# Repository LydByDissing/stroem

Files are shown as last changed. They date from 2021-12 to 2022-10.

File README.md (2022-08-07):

# STRØM
**An Open Wifi Speaker**

The _Strøm_ open source speaker project have been started with the main goal of creating a fully functional "wifi speaker", but as an open sourced product.

## License
This project and all it's work are licensed under the [Creative Commons Attribution-ShareAlike 4.0 International License](http://creativecommons.org/licenses/by-sa/4.0/) license.




## Getting started

### Checking out the repository
As this project uses the git `submodule` feature to fetch all the needed source files, one would need to have this in mind when performing the checkout.

To checkout everything - including all submodules - the following snippet are handy:
```
git clone --recurse-submodules -j$(nproc) https://github.com/LydByDissing/stroem.git
```

## Project description and Design Goals
As mentioned above, this project aims at designing a **wifi speaker**, capable of streaming audio using **Bluetooth** and **Spotify Connect**.

The primary design goals of the _Strøm_ speaker are:

* Minimalistic design language
* Playback via Spotify Connect and Bluetooth
* Wall mountable
* Sustainable materials
* Open Source

Making it a modern, minimalistic and fully capable speaker. Further requirement details can be found in the [requirements document](https://stroem.readthedocs.io/en/latest/requirements.html).

Besides making a modern and capable wifi speaker we are also aiming at validating the concept of "local manufactoring" - how we exactly are going to succeed with this are still an unanswered questions; see [issue #5](https://wikifactory.com/+opennext/lydbydissing/issues/local-production-but-how) for further discussions on the matter.

## Open Next Demonstrator
This project takes part in Open Next 2022 as a demonstrator project - one of twelve to be exact.
Most Strøm and Open Next communication will happen over at [this](https://wikifactory.com/@sidsel/osd-platform-for-maker) page.

## Project Documentation

The main project documentation and any permanent documentation are written in the `reStructuredText` (`.rst`) format, using the [Sphinx documentation framework](https://www.sphinx-doc.org/en/master/).

The code resides in the Strøm GitHub repo ([LydByDissing/stroem](https://github.com/LydByDissing/stroem)) and the compiled documentation are available over at Read The Docs: [stroem.readthedocs.io](https://stroem.readthedocs.io/).

## Contributions and collaboration
We love contributions! And all forms of contributions and collaborations are welcome.

The development of the speaker and most of the involved parts are tracked here at [LydByDissing/stroem](hhttps://github.com/LydByDissing/stroem).
The main documentation of the project, the parts and the assembly process and any permanent documentation are documented using the Sphinx documentation framework as mentioned above.

### Want to participate, but not sure where to start?
Take a look at one of the open [issues](https://github.com/LydByDissing/stroem/issues) already created and chip in with your knowledge and experience. Sometimes all it takes is a single comment, to push a someone else in the right direction; so don't hold yourself back.

Or read our [contributing guidelines](https://github.com/LydByDissing/stroem/blob/main/CONTRIBUTING.md) for further details on how to be involved.

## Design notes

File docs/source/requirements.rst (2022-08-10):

.. _Requirements:

Requirements
############
The main goal of the *Strøm* open source speaker project are to create a fully functional and open source "wifi speaker".

The Speaker concept
===================
The primary features of the *Strøm* speaker are:

* Minimalistic design language
* Playback via Spotify Connect and Bluetooth
* Wall mountable
* Sustainable materials
* Open Source

Making it a modern, minimalistic and fully capable speaker.

Design Goals
============
The following parameters are used as design goals. These are not *hard* requirements, but reflects the ideal characteristics of the final speaker.

Sustainability
**************
It is important to use materials that are produced and sourced using sustainable methods, as well as using sustainable productions methods of the speaker itself.
A non exhaustive lists of considerations:

* The cabinet must primarily be made out of wood

  * like MDF and plywood
* No plastic
* Built to be repairable

Making a 100% sustainable active speaker is, however, not 100% realistic as there isn't any fully sustainable PCB's. At least not readable available.

Cabinet
*******
The design of the cabinet must reflect a minimalistic design approach. This means a small physical form factor and a minimalist visual appearance.
A non exhaustive lists of considerations:

* Small form factor
* Shallow cabinet for better on-wall placement
* Ultra mat finish of the cabinet
* Cloth covered drivers

Acoustics
*********
With this project it is not the goal to create another `boombox <https://en.wikipedia.org/wiki/Boombox>`_, with over attenuated lows (bass) and highs (treble) as this will quickly result in listening fatigue. This is also called a `smiley face curve <https://en.wikipedia.org/wiki/Smiley_face_curve>`_.

However a slight bass boost at lower SPL levels to accommodate for the non-linear human hearing will make the speaker sound natural at lower sound pressure levels (SPL). This boost should be less pronounced at higher SPL levels; the dynamic part of this requirement can become hard to realize, but it will make for a much more appealing listening proposition.
A non exhaustive lists of further considerations:

.. acoustic-requirements-start

* Max SPL of 100dB
* Frequency range: 80Hz - 17kHz; ±3dB
* Reasonable flat response; within ±4dB
* High speech intelligibility
* SPL dependent bass boost to match the nonlinearity of the human hearing

.. acoustic-requirements-end

Below each of the technical design goals are unwrapped to explain what they mean and how the voicing process is used to implemented these requirements.

High maximum SPL
----------------
:abbr:`SPL (Sound Pressure Level)` is a measure of "how loud" a sound is. And the maximum SPL of a speaker tells something about how loud a speaker is capable of playing.

Usually the SPL is measured at a distance of one meter [m]. The unit of SPL is decibel [dB].

The Strøm speaker isn't a large speaker, but it should still be a capable speaker. A speaker that is capable of "playing loud". But as this can be hard to quantify as the perception of "loud" various a great deal from person to person. It is also highly affected by the distance between the speaker and the listener as well as it's placement in the room.
And finally this perception is impacted by any audible distortion from the speaker. The higher the distortion, the higher the SPL is perceived.

So instead of stating that the speaker must play "loud", a quantifiable number is needed.

We also want to add a few more limitations to this design goal. The maximum SPL should:

* be reachable "anywhere" on the frequency band,

* without reaching the mechanical limits of the driver,

* and should avoid clipping

We have settle on **100dB of maximum SPL** for this small speaker. This will be more than sufficient for most small and medium sized rooms.
The implementation of this requirement will affect (limit) the frequency response of the speaker. Most drivers can play down to 20Hz, but maybe not at great volume. So by limitting the frequency band we can push the drivers to higher SPL levels.

Frequency response
------------------

It should be pleasent to listen to this speaker and at the same time you should be able to get an "audio experience". So no smiley curve frequency response, nor overly exaggerated lows; i.e. this is not a boom box. We are looking to implement a "hi-fi" speaker with fairly linear frequency response.

A requirement of a linearity within ±4dB isn't perfect, but it is a pretty decent middle ground.

The better the low range extension a speaker can achieve, the more of the audio frequency range it is capable of reproducing and the more "convincing" this speaker will sound.

As small drivers are used, subwoofer levels of extension are hard to come by, so a compromise is needed. By setting the targeted -3dB point at 80Hz, this speaker will not be a bass monster, but the bass it will reproduce will be crips and undistorted.

When placed on a wall even lower frequency extension will be possible at the same (or higher) SPL.

Drivers
=======
In order to fulfill the requirements of a small form factor speaker, shallow drivers are needed. This makes it possible to minimize the overall depth of the cabinet.

Only a few really larger shallow drivers exists, which also tends to be rather expensive. They usually deliver good performance, but most of them are considered to be too expensive for this project.
In stead of using one large driver, 4 miniature full range transducers are targeted instead. This makes it possible to decrease the overall depth of the cabinet.

The following drivers are used:

* 2.5" full range driver: :ref:`SB65WBAC25-4 <full-range-driver>`.

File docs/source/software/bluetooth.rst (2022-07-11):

.. _bluetooth:

=========
Bluetooth
=========

.. epigraph::

  *"A short-range wireless technology standard that is used for exchanging data between fixed and mobile devices over short distances"*

  -- `Wikipedia <https://en.wikipedia.org/wiki/Bluetooth>`_

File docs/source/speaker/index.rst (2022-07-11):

**************************
Speaker Parts and Assembly
**************************

The speaker cabinet are constructed from MDF, as this material is well suited for this type of application. Both the low internal damping, as well as the ease of processing, of this material makes it a good choice for constructing speaker cabinets.

To minimize the overall volume of the cabinet, a sealed construction is chosen. Each driver, does in fact, have its own internal cabinet. This is done to minimize the internal interference between the drivers; hence limiting interference artifacts.

Each speaker part have its own unique ID to make it easier to identify the correct part. Externally sourced parts will likely also have a SKU or similar.

.. toctree::
   :maxdepth: 1
   :glob:

   parts/index
   assembly/index

Cabinet construction
====================

To ensure an easy assembly of the speaker cabinet, a sandwish construction is used. This makes it easy to construct the different layers and, at the same time, simplifying the construction of this semi complex cabinet. This also makes it possible to machine all the individual layers on a CNC.
This comes in handy when utilizing `decentrilized manufactoring <https://en.wikipedia.org/wiki/Distributed_manufacturing>`_.

Further details on the cabinet assembly can be found in the :ref:`assembly section <Cabinet Assembly Description>`.

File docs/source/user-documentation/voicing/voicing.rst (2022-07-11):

Voicing of the *Strøm* speaker
##############################

.. note::
  One important aspect of developing a speaker are to tune the frequency response, as well as to ensure that the drivers isn't driven over their capabilities.
  It is here the sound of the speaker is developed.

  This process is called **voicing**.

The voicing of a speaker consists of several steps and this *howto* will try to outline a few of them. The following topics will be covered below:

* Voicing goals
* Measurements
* Adjusting the response

Voicing goals
-------------

With the Strøm speaker several design goals have been defined (see more in the :ref:`Requirements` section) and those related to sound reproduction should – where applicable – be implemented through the voicing process.

The following acoustic design goals have been set for the speaker:

.. include:: ../../requirements.rst
  :start-after: acoustic-requirements-start
  :end-before: acoustic-requirements-end

Most of these design goals can be asserted using various measurement techniques.

Measuring the speaker
---------------------

What you need to measure the speaker:

* A measurement microphone like the `UMIK-1 <https://www.minidsp.com/products/acoustic-measurement/umik-1>`_ (or similar)
* Assembled cabinet with drivers
* External amplifier
* Laptop (or similar) with `Camilla DSP <https://github.com/HEnquist/camilladsp>`_ installed.
* Room EQ Wizard (`REW <https://www.roomeqwizard.com>`_)

In order to measure the speaker, make sure that you can *"answer yes"* to all of the above bullets.

What do we want to measure?
___________________________

With ``REW`` it is possible to measure a large suite of things, but bare in mind, that this program is initial created to measure rooms and not speakers.
We will use ``REW`` to perform the following measurements:
* frequency response
* phase response
* impulse response

Frequency and phase response
____________________________

We do not have easy access to an anechoic chamber, but that doesn't mean that we can't produce some useful results. And for this speaker we actively rely on the walls and boundaries to increase our bass response. So a measurement "in place" isn't actually that bad.

We have placed the microphone within 10cm from the baffle to limit the impact of reflections.

Here's the speaker measured before voicing. A single 8th order high pass (HP) filter have been added at 45Hz to protect the driver (from exceeding :math:`X_{max}`).

The frequency and phase response are depicted. It is worth noting that the results haven't been normalize, resulting in that the measured dB can't be related to anything (other than other measurements using the same setup).

.. chart:: user-documentation/voicing/80hz-target-no-filter-frequency-response.json

    Measured frequency response of an initial test cabinet. Primarily used for validation of the internal cabinet volume.

Adjusting the response
----------------------

As a developement workflow I am using the great `HEnquist/camilladsp <https://github.com/HEnquist/camilladsp>`_ project. This makes it possible to specify the filter banks as a simple YAML config file. For the initial 80Hz target tuning this file have been used: `voicing/voicing-80hz-target.yaml <https://github.com/LydByDissing/stroem/tree/main/voicing>`_.

As we can't make the bass higher – without additional :math:`X_{max}` of the driver - we need to lower the rest of the frequency response. This will lower the overall efficiency of the speaker, but result in a much more linear frequency response. See the below graph for a measurement of the inital filters applied to the signal chain.

.. chart:: user-documentation/voicing/80hz-target-initial-filters-frequency-response.json

    Measurement result when initial filtering have been applied.

The result isn't perfect but a really good starting point (and a good sounding one of that) which proves that these little drivers are pretty capable in this little cabinet.

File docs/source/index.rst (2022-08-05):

.. |date| date::

#########################################
An Open Source Wireless Streaming Speaker
#########################################

The *Strøm* open source speaker project have been started with the main goal of creating a fully functional "streaming speaker", but as an open sourced product. One that you can choose to buy fully built and tested, or choose to built it yourself.

.. toctree::
  :caption: Documentation Sections
  :maxdepth: 1

  requirements
  user-documentation/index
  repair
  end-of-life
  speaker/index
  software/index
  contributing
  license
  todo
  changelog

Read on below to get a high level `Introduction to the project`_ as a whole.

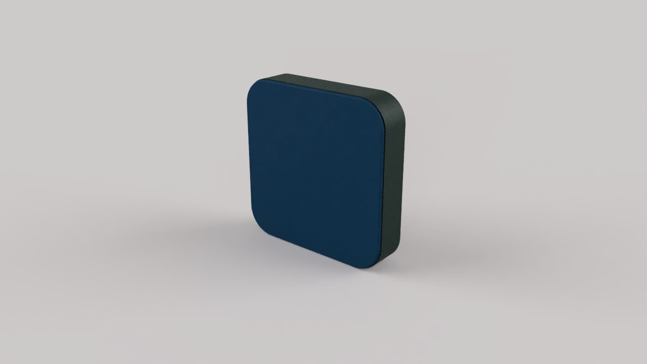
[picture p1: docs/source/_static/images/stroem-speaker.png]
Speaker


   Strøm speaker in conifer linoleum and blue fabric on the soft top.

Introduction to the project
###########################

The primary features of the *Strøm* speaker are:

* Minimalistic design language
* Playback via Spotify Connect and Bluetooth
* Wall mountable
* Sustainable materials

Making it a modern, minimalistic and fully capable speaker.

Motivation for starting the STRØM 1.0 project
*********************************************

Project goals
*************

Project history
***************

Initially started as an OPEN!NEXT demonstrator project in December 2021. The project was started by Tue Dissing.

Contributing to the project
***************************

Interested in contributing to the project? Then please take a quick look at the contribution guideline beforehand.
You find the contribution guide :ref:`here <contribution guideline>` and in the GitHub repo as well: `LydByDissing/stroem/CONTRIBUTING.md <https://github.com/LydByDissing/stroem/blob/main/CONTRIBUTING.md>`_.

Last updated
************
The mainline documentation have last been updated at |date|.

License
#######

This project is licenced under the :ref:`Creative Commons ShareAlike 4.0 license <license>`.

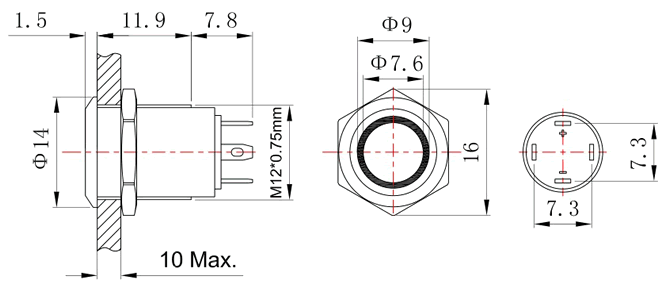
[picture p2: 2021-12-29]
docs/source/speaker/parts/push-button/12QD21-spec.gif

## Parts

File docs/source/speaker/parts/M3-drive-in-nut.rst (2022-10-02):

.. _drive-in nuts:

Drive-in Nut
************

.. sidebar:: Parts information
  :subtitle: See the below for a quick overview of the naming and ID information of this part.

  | **Part name**: *M3 Screw; 0376 3 5*
  | **Parts ID**: 6C27ST
  | **Product link**: `Würth 0376 3 5 <https://eshop.wuerth-industrie.com/Drive-in-nut-NUT-DRIVIN-A2K-H5X12-M3/03763%20%205.sku/en/US/EUR/>`_

Parts Description
-----------------
To ensure proper mounting of the speaker drivers, they are fastened using these screws and the already mounted drive-in nuts.

Please see the tables below for dimensions.

.. table:: Physical requirements

  +--------------+------------------+-----------+
  | Screw type   | Outer dimensions | Thread    |
  +==============+==================+===========+
  | Drive-in nut | 5mm x 13mm       | M3        |
  +--------------+------------------+-----------+

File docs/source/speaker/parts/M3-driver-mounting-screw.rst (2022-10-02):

M3 driver mounting screw
************************

.. sidebar:: Parts information
  :subtitle: See the below for a quick overview of the naming and ID information of this part.

  | **Part name**: *M3 DIN7985 screw; 004648 316*
  | **Parts ID**: 3A4RA6
  | **Product link**: `Würth 004648 316 <https://eshop.wuerth.dk/Maskinskrue-MSKRUE-DIN7985-48-PH-H1-BRU-3X16/004648%20316.sku/da/DK/DKK/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>`_

Parts Description
-----------------
To ensure proper mounting of the speaker drivers, it's not enough to just drive the screws into the MDF of the baffle. We need mounting hardware to ensure that the drivers remain in place. A set of :ref:`Drive-in nuts <drive-in nuts>` are mounted on the backside of the :ref:`baffle <cabinet baffle>`. These screws are fasted into the nuts, holding the drivers in place.

Please see the tables below for dimensions.

.. table:: Physical requirements

  +-----------------------+------------------+--------+
  | Type                  | Outer dimensions | Thread |
  +=======================+==================+========+
  | M3 metal screw; black | 6mm x 16mm       |  M3    |
  +-----------------------+------------------+--------+

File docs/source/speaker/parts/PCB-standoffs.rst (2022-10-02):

PCB Standoffs
*************

.. sidebar:: Parts information
  :subtitle: See the below for a quick overview of the naming and ID information of this part.

  | **Part name**: *PCB Standoff; 0968 000310*
  | **Parts ID**: 3A4RA6
  | **Product link**: `Würth 0968 000310 <https://eshop.wuerth.dk/Stalafstandsbolt-AFSTANDSSTYKKE-NV6-FZB-3X10MM/0968000310.sku/da/DK/DKK/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>`_

Parts Description
-----------------
The PCB are mounted inside the main cabinet. There are dedicated support for this on :ref:`cabinet layer 1 <cabinet layer 1>`. here a set of drive-in nuts are mounted. Using a set (of four) PCB standoffs the PCB are securely mounted to the cabinet. This provides sufficient space on both sides of the PCB.

Please see the tables below for dimensions.

.. table:: Physical requirements

  +---------------------+-------------------+-----------+
  | Type                | Outer dimensions  | Thread    |
  +=====================+===================+===========+
  | Steel PCB standoffs | 6mm X 16mm        | M3        |
  +---------------------+-------------------+-----------+

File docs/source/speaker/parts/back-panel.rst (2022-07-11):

Back Panel
**********

.. sidebar:: Parts information
  :subtitle: See the below for a quick overview of the naming and ID information of this part.

  | **Part name**: *Back Panel*
  | **Parts ID**: NMOIMO
  | **Material**: 6mm,   MDF

Part description
----------------
The cabinet back panel are the bottom layer in the complete cabinet. This part makes an air tight fit to the rest of the cabinet, sealing the enclosure.

Four counter sunk screw holes -- one in each corner -- are created in this part for easy assembly.

To ensure a close distance between the back panel and the wall, when wall mounted, a bracket needs to be recessed into this part. This bracket must be fastened with two wood screws.

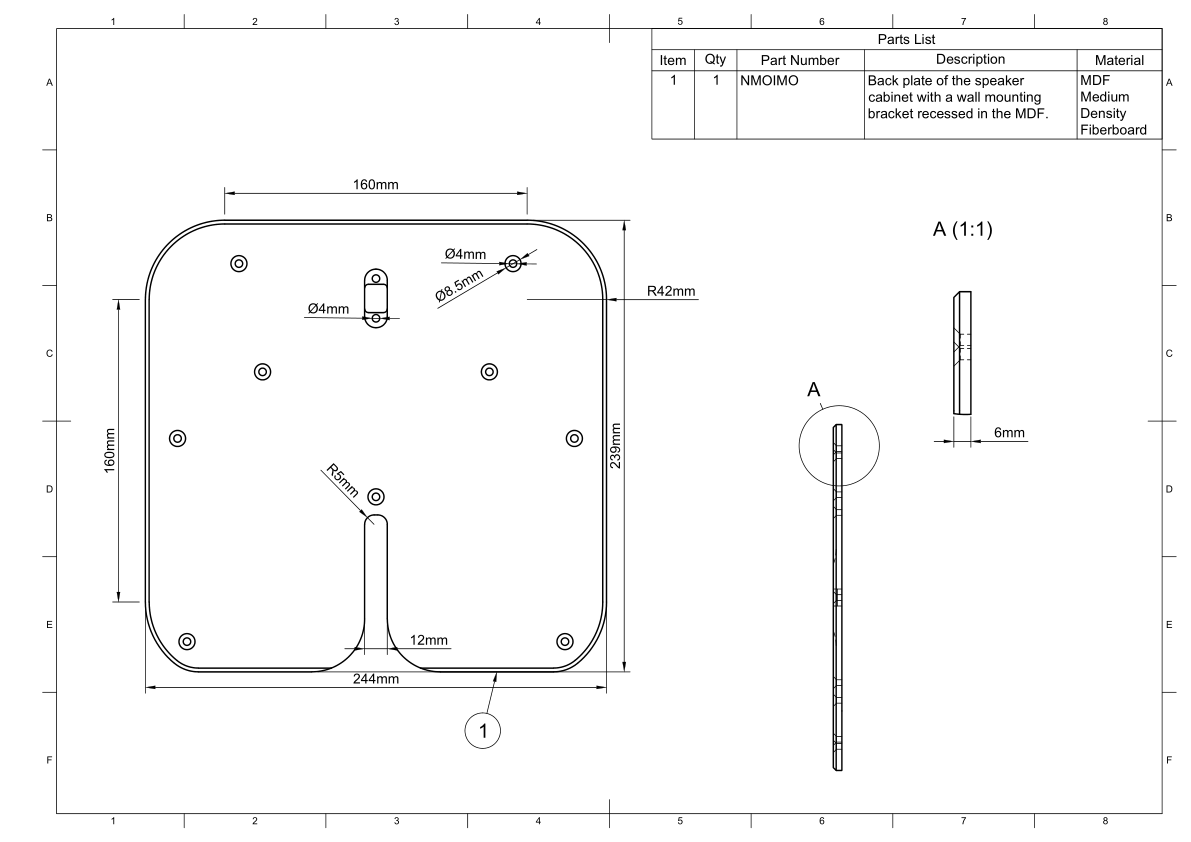
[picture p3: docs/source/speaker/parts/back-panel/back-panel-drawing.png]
Drawing with measurements of the back panel


Finish
------
To create a small visual seperation between the wall and the speaker, the back panel must be of a dark color. Preferably black.
The most important part of the back panel to finish with a black tint, are the 45° angled sides.

.. warning::
  Depending on the requirements with regards to MDF degassing, this cabinet part only needs limited finishing, or a full pain job.

Downloads
---------

Download the drawing as a PDF :download:`back-panel-drawing.pdf <back-panel/back-panel-drawing.pdf>`.

Download the CAD file in .STEP format :download:`back-panel.step <../../../../CAD/back-panel.step>`.

.. panels::
    :column: col-lg-12

    Fusion 360 Source Files
    ^^^^^^^^^^^^^^^^^^^^^^^

    *The model is developed in Fusion 360. To access the original Fusion 360 source files, follow the link below.*

    .. link-button:: https://a360.co/3c2rJig
        :classes: btn-success
        :text: Access source files

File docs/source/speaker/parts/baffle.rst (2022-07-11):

.. _cabinet baffle:

Cabinet Baffle
**************

.. sidebar:: Parts information
  :subtitle: See the below for a quick overview of the naming and ID information of this part.

  | **Part name**: *Baffle*
  | **Parts ID**: 47TTHC
  | **Material**: 12mm, MDF

Part description
----------------
The baffle are where the speaker drivers are mounted. They are counting sunk into the baffle, so the top of the driver matches the top of the baffle.
For each driver four screw holes are made to fasten the driver to the baffle.

Three assembly-guiding holes are also cut in to the baffle. This helps aligning the different layers with each other.

.. seealso::
  For further details about the assembly, take a closer look at the :ref:`assembly description <Cabinet Assembly Description>`.

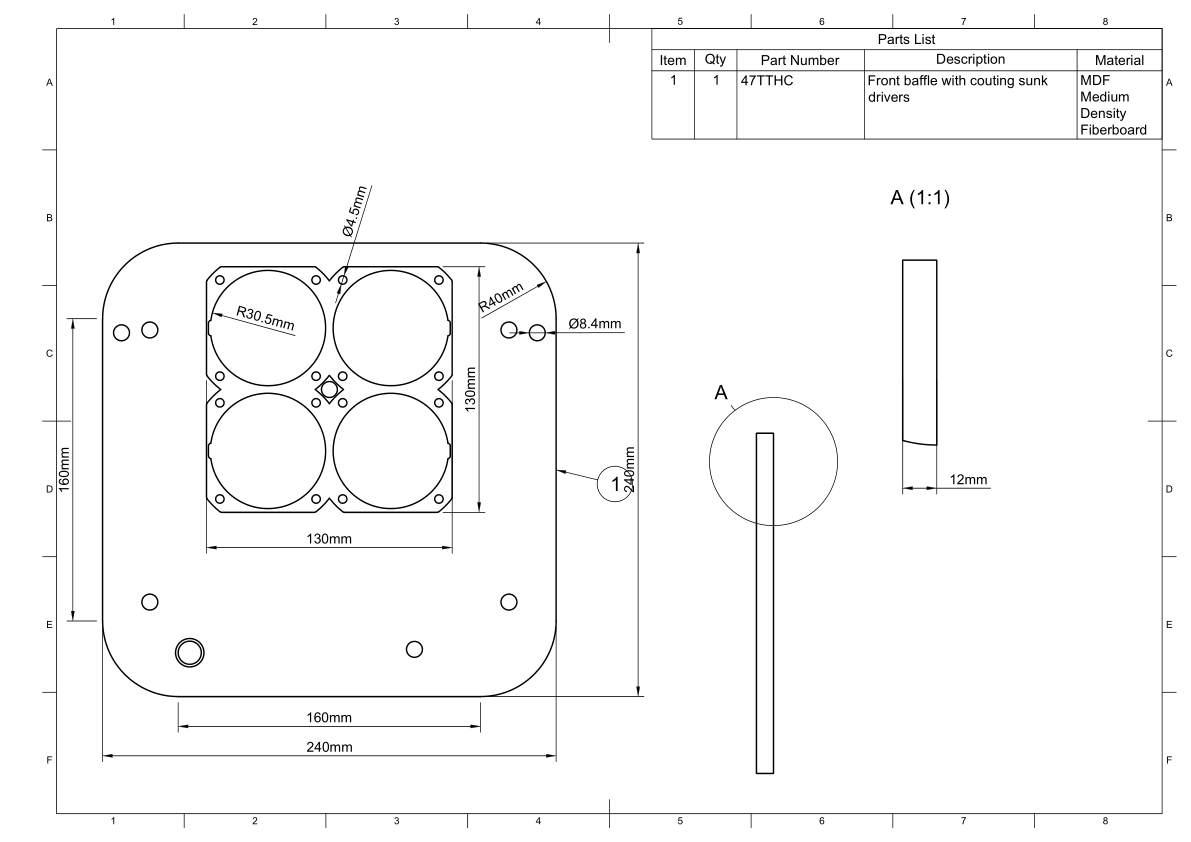
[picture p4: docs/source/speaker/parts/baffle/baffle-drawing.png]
Drawing with measurements of the baffle


.. todo:: Add feature to ensure proper mounting of the :ref:`soft top frame <Soft Top Frame>` to the baffle.

Finish
------
The top of the baffle must be finished with a paint, complementary to the hue of the :ref:`soft top fabric <Soft Top Fabric>`. If the fabric are of a light hue, then a white paint must be applied -- `RAL9010 <https://www.ralcolorchart.com/ral-classic/ral-9010-pure-white>`_ for instance -- and when are darker hue of fabric are used, then a black finish must be applied -- something like `RAL9005 <https://www.ralcolorchart.com/ral-classic/ral-9005-jet-black>`_ will suffice.

The surface finish of the paint are allowed to be a rough and matte finish, as the top of baffle are covered by the soft top fabric under normal operation.

.. warning::
  Depending on the requirements with regards to MDF degassing, this cabinet part only needs limited finishing, or a full pain job.

Downloads
---------

Download the drawing as a PDF :download:`baffle-drawing.pdf <baffle/baffle-drawing.pdf>`.

Download the CAD file in .STEP format :download:`baffle.step <../../../../CAD/baffle.step>`.

.. panels::
    :column: col-lg-12

    Fusion 360 Source Files
    ^^^^^^^^^^^^^^^^^^^^^^^

    *The model is developed in Fusion 360. To access the original Fusion 360 source files, follow the link below.*

    .. link-button:: https://a360.co/3IsP1Zk
        :classes: btn-success
        :text: Access source files

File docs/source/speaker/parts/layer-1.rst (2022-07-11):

.. _cabinet layer 1:

Cabinet Layer 1
***************

.. sidebar:: Parts information
  :subtitle: See the below for a quick overview of the naming and ID information of this part.

  | **Part name**: *Cabinet layer 1*
  | **Parts ID**: 5R9GCA
  | **Material**: 12mm, MDF

Part description
----------------

This is the first layer of the cabinet, connecting directly to the baffle.
To make room for the DC barrel power plug and it's wires, a mounting hole and a tapering slot are cut. This helps guide the DC power cables from the DC socket.

The three larger holes (Ø8,4mm) are for dowels, used for aligning the three layers during cabinet assembly.

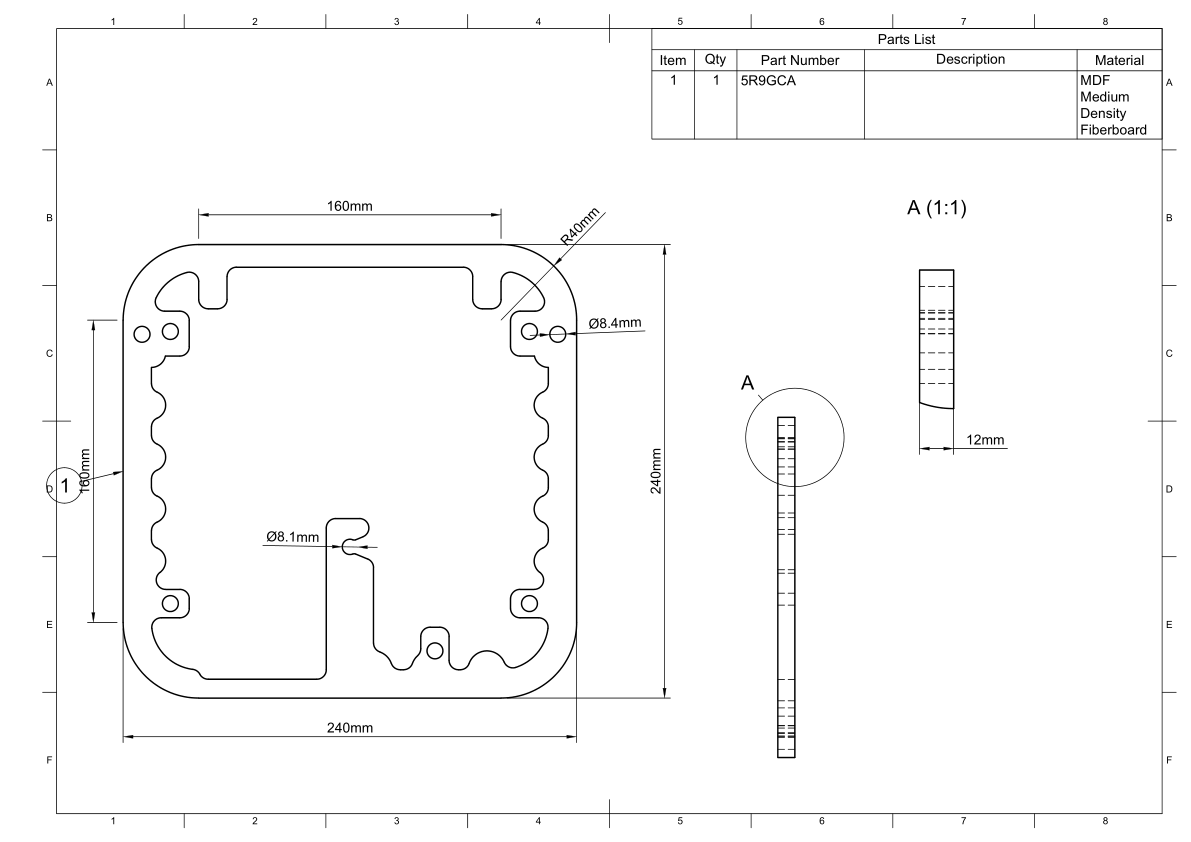
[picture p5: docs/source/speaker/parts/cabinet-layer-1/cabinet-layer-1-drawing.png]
Drawing with measurements of the back panel


Finish
------

This part doesn't require any finish.

Downloads
---------

Download the drawing as a PDF :download:`cabinet-layer-1-drawing.pdf <cabinet-layer-1/cabinet-layer-1-drawing.pdf>`.

Download the CAD file in .STEP format :download:`cabinet-layer-1.step <../../../../CAD/cabinet-layer-1.step>`.

.. panels::
    :column: col-lg-12

    Fusion 360 Source Files
    ^^^^^^^^^^^^^^^^^^^^^^^

    *The model is developed in Fusion 360. To access the original Fusion 360 source files, follow the link below.*

    .. link-button:: https://a360.co/3Pi2yXs
        :classes: btn-success
        :text: Access source files

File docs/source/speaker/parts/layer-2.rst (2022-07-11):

.. _cabinet layer 2:

Cabinet Layer 2
***************

.. sidebar:: Parts information
  :subtitle: See the below for a quick overview of the naming and ID information of this part.

  | **Part name**: *Cabinet layer 1*
  | **Parts ID**: 5R9GCA
  | **Material**: 12mm, MDF

Part description
----------------

This is the middle layer of the cabinet. To make room for the DC barrel power socket, a matching DC socket mounting hole is cutout. Half of this hole are counter sunk at a wider diameter (Ø11,5) to accommodate for the wider diameter of the DC plug itself - to ensure that this plugin can be fully consealed within the cabinet (for on wall placement).

The small holes (Ø2mm) are used when mounting the back plate to the main cabinet.
The larger holes (Ø8,4mm) are for dowels, used for aligning the three layers during cabinet assembly.

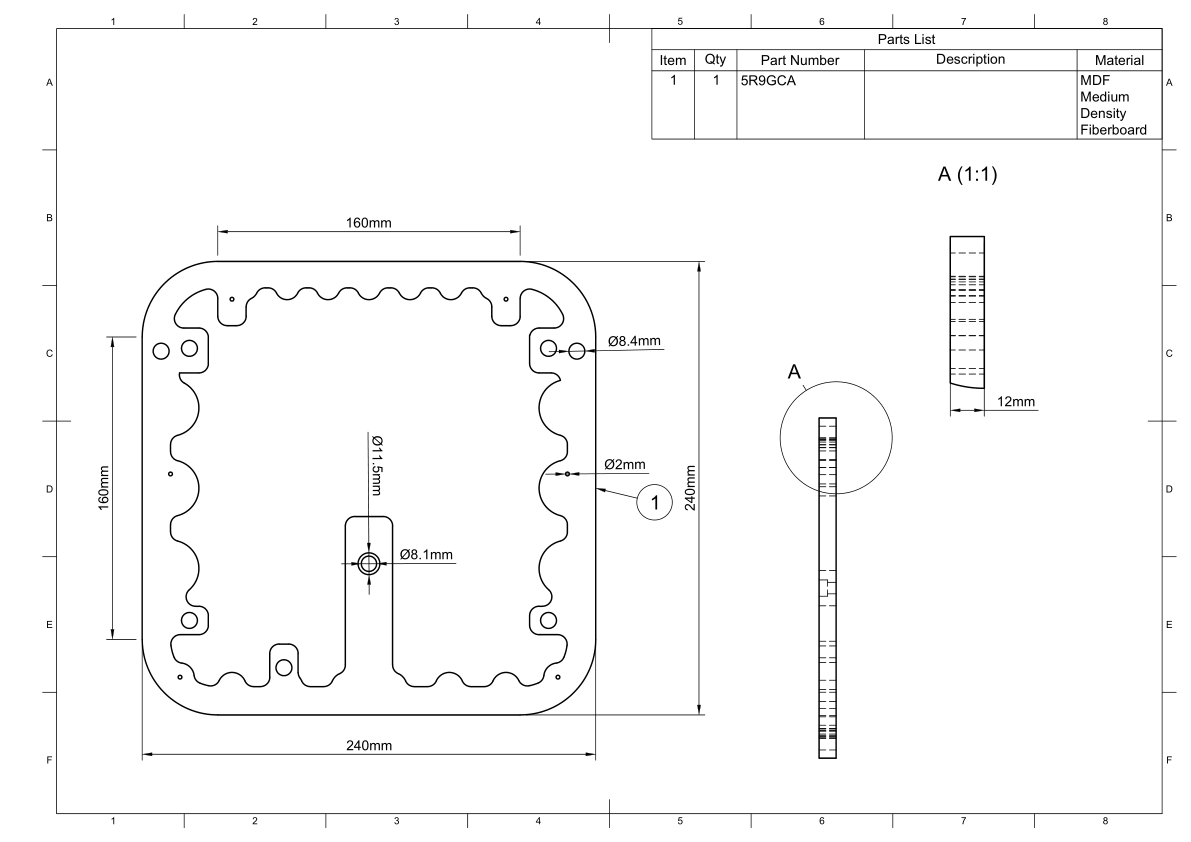
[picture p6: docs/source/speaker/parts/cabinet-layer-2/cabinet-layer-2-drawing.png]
Drawing with measurements of the back panel


Finish
------

This part doesn't require any finish.

Downloads
---------

Download the drawing as a PDF :download:`cabinet-layer-2-drawing.pdf <cabinet-layer-2/cabinet-layer-2-drawing.pdf>`.

Download the CAD file in .STEP format :download:`cabinet-layer-2.step <../../../../CAD/cabinet-layer-2.step>`.

.. panels::
    :column: col-lg-12

    Fusion 360 Source Files
    ^^^^^^^^^^^^^^^^^^^^^^^

    *The model is developed in Fusion 360. To access the original Fusion 360 source files, follow the link below.*

    .. link-button:: https://a360.co/3yvXRT8
        :classes: btn-success
        :text: Access source files

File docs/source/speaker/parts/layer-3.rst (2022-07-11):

.. _cabinet layer 3:

Cabinet Layer 3
***************

.. sidebar:: Parts information
  :subtitle: See the below for a quick overview of the naming and ID information of this part.

  | **Part name**: *Cabinet layer 1*
  | **Parts ID**: 7SCERM
  | **Material**: 12mm, MDF

Part description
----------------

This is the third layer of the cabinet - counting form the baffle. Here a large keyhole slot a cut to make room for the DC jack, an L-bracket adaptor and a little wire. All in all to make sure that the power connections are consealed when mounted to a wall.

The small holes (Ø2mm) are used when mounting the back plate to the main cabinet.
The larger holes (Ø8,4mm) are for dowels, used for aligning the three layers during cabinet assembly.

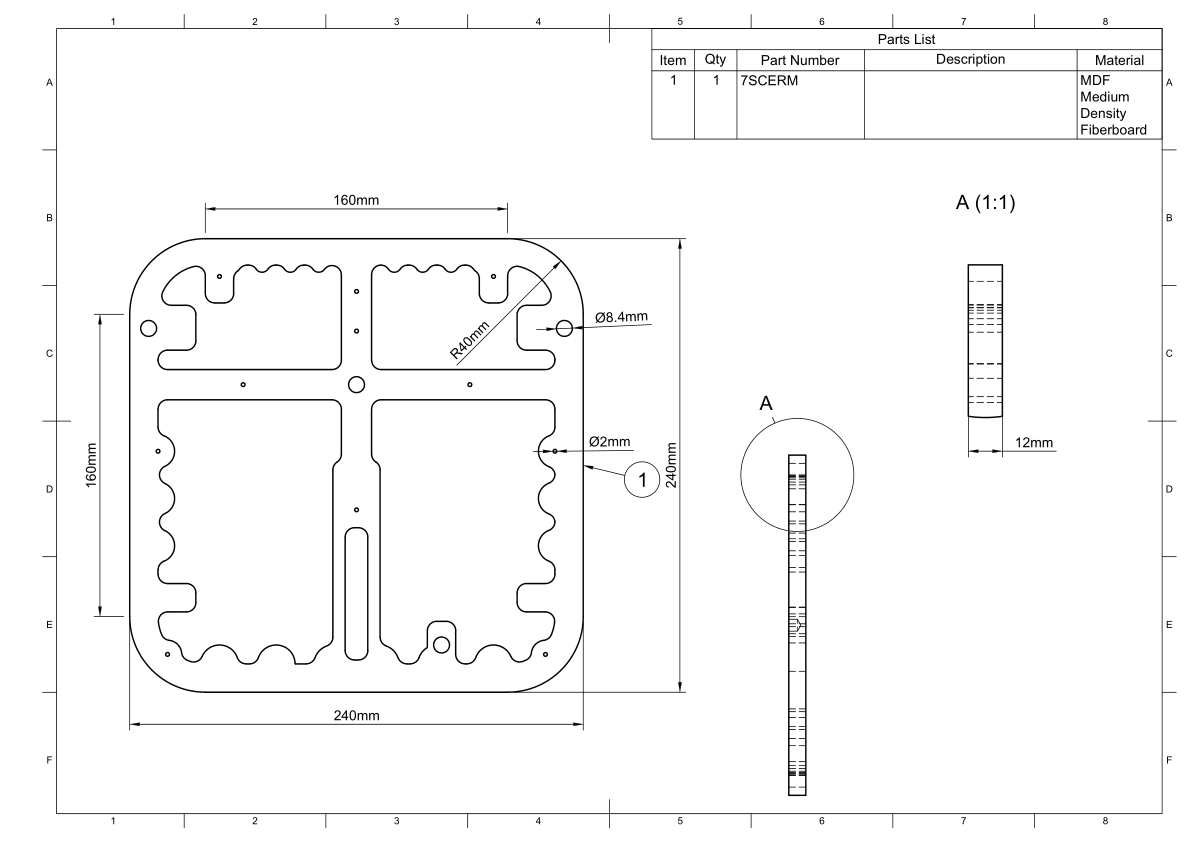
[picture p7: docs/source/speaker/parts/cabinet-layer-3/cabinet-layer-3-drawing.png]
Drawing with measurements of the back panel


Finish
------

This part doesn't require any finish.

Downloads
---------

Download the drawing as a PDF :download:`cabinet-layer-3-drawing.pdf <cabinet-layer-3/cabinet-layer-3-drawing.pdf>`.

Download the CAD file in .STEP format :download:`cabinet-layer-3.step <../../../../CAD/cabinet-layer-3.step>`.

.. panels::
    :column: col-lg-12

    Fusion 360 Source Files
    ^^^^^^^^^^^^^^^^^^^^^^^

    *The model is developed in Fusion 360. To access the original Fusion 360 source files, follow the link below.*

    .. link-button:: https://a360.co/3c8Ejg5
        :classes: btn-success
        :text: Access source files

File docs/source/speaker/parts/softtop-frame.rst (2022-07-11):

.. _Soft Top Frame:

Soft Top Frame
**************

.. sidebar:: Parts information
  :subtitle: See the below for a quick overview of the naming and ID information of this part.

  | **Part name**: *Soft top frame*
  | **Parts ID**: UIV56C
  | **Material**: 6mm, MDF

Part description
----------------

The soft top frame holds the fabric that covers the drivers. This is a simple part.
The soft top frame are friction fit to the pretuding dowels in hte baffle of the main cabinet. This ensures a tight fit of the frame but at the same time allow for its removal in case of service or repair.

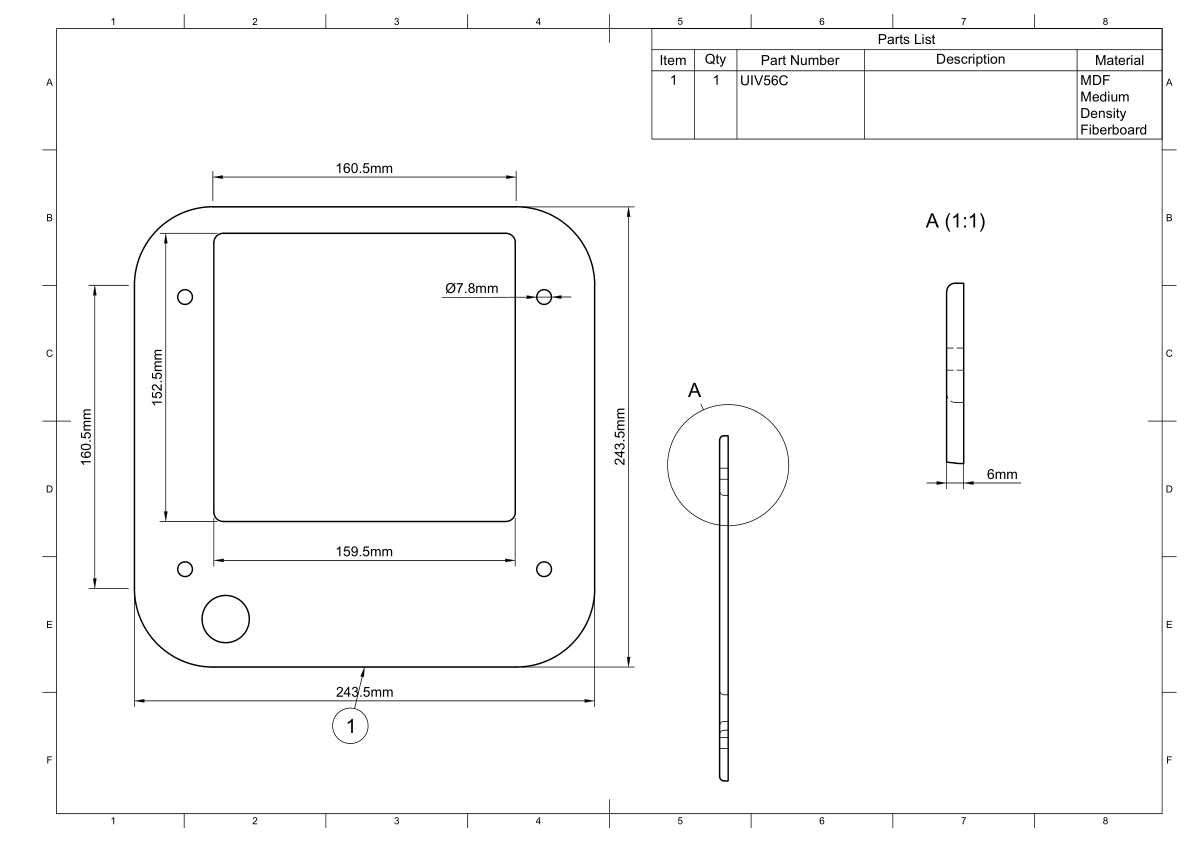
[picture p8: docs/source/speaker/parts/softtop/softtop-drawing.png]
Drawing with measurements of the soft top frame


Finish
------
This part is painted black to match the shadow created where the drivers are located.
It is important to lightly sand this part after painting, as the raised grain can in fact tare any fragile fabric.

Downloads
---------

Download the drawing as a PDF :download:`softtop-drawing.pdf <softtop/softtop-drawing.pdf>`.

Download the CAD file in .STEP format :download:`softtop.step <../../../../CAD/softtop.step>`.

  .. panels::
      :column: col-lg-12

      Fusion 360 Source Files
      ^^^^^^^^^^^^^^^^^^^^^^^

      *The model is developed in Fusion 360. To access the original Fusion 360 source files, follow the link below.*

      .. link-button:: https://a360.co/3OXEYPO
          :classes: btn-success
          :text: Access source files

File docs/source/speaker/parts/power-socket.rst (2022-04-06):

.. _Power connector:

DC Power Socket
***************

.. sidebar:: Parts information
  :subtitle: See the below for a quick overview of the naming and ID information of this part.

  | **Part name**: *DC power socket*
  | **Parts ID**: I6C3Q5
  | **Manufactor**: `Tensility <https://tensility.com>`_
  | **Manufactor ID**: 50-00541
  | **Product link**: `Tensility 50-00541 <https://tensility.com/connectors/50-00541>`_

Parts Description
-----------------

In order to maintain an airtight cabinet we have taken a bit of a different approach to the DC socket. In fact this socket is a overmold jack. We are then using the cabinet as the overmold.



How this socket are integrated in the cabinet are described in detail in the :ref:`assembly description <Cabinet Assembly Description>` as well as in the description of layer :ref:`2 <cabinet layer 2>` and :ref:`3 <cabinet layer 3>`.

.. todo:: the assembly section needs to be updated.

Sourcing
--------

.. todo:: sourcing of this module are still TBD.

Downloads
---------

Download the specification as a PDF :download:`50-00541.pdf <https://tensility.s3-us-west-2.amazonaws.com/uploads/product_doc/document/2319/50-00541.pdf>`.

Download the CAD file in .STEP format :download:`50-00541.step <https://tensility.com/download_3d_model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>`.

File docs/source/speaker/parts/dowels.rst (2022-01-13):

:partsId: OOWEOE

.. _`dowels`:

Dowels
******

.. sidebar:: Parts information
  :subtitle: See the below for a quick overview of the naming and ID information of this part.

  | **Part name**: *Dowels*
  | **Parts ID**: OOWEOE
  | **Material**: *8mm, wood*

When assembling the cabinet dowels are needed for easy alignment of the different layers.

Parts description
-----------------

These woods dowels comes in many assortments, lengths and diameters. For this project the following dimensions dowels are needed:

.. table:: Physical requirements for dowels.

  +----------+----------+--------+
  | Material | Diameter | length |
  +==========+==========+========+
  | Wood     + 8mm      + 40mm   +
  +----------+----------+--------+

An example of such as dowel are this one from HABO: `63009 <https://habo.com/dk/sortiment/mobelbeslag/monteringsbeslag/traedyvel-63009>`_.

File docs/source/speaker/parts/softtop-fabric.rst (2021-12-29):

.. _Soft Top Fabric:

Soft Top Fabric
***************

.. sidebar:: Parts information
  :subtitle: See the below for a quick overview of the naming and ID information of this part.

  | **Part name**: *Soft top cloth*
  | **Parts ID**: 0NGII0
  | **Material**: Jersey fabric

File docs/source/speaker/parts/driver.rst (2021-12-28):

.. _full-range-driver:

Full Range Driver
*****************

.. sidebar:: Parts information
  :subtitle: See the below for a quick overview of the naming and ID information of this part.

  | **Part name**: *Driver; SB65WBAC25-4*
  | **Manufactor**: `SB Audience <http://www.sbaudience.com>`_
  | **Manufactor ID**: SB65WBAC25-4
  | **Parts ID**: 7SQ7QH
  | **Product link**: `SB Audience SB65WBAC25-4 <http://www.sbaudience.com/index.php/products/various-drivers/sb65wbac25-4/>`_

Parts Description
-----------------
This is the full range driver used in this project. For each speaker a total of four drivers are needed.

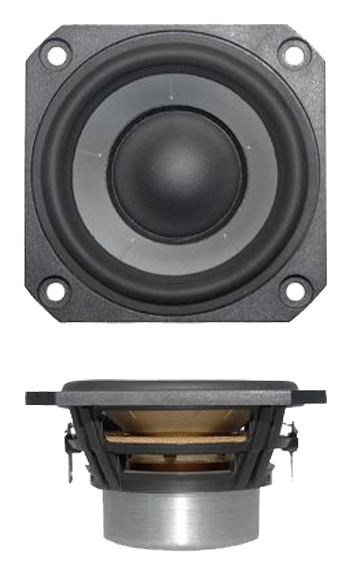
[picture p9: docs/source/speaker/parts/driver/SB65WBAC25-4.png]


These drivers are primarily chosen for their extremely small height -- of only 38mm overall height -- and for their relative high power handling of 20W.

Sourcing
--------
.. todo:: sourcing of this module are still TBD.

Downloads
---------
Download the driver specification as a PDF :download:`2.5in SB65WBAC25-4.pdf <driver/2.5in SB65WBAC25-4.pdf>`.

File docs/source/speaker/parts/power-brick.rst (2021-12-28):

Power Brick
***********

.. sidebar:: Parts information
  :subtitle: See the below for a quick overview of the naming and ID information of this part.

  | **Part name**: *Power brick; GST60A18-P1J*
  | **Parts ID**: WVOAE2
  | **Product link**: `Mean Well GST60A18-P1J <https://www.meanwell-web.com/en-gb/ac-dc-industrial-desktop-adaptor-output-18vdc-at-3-gst60a18--p1j>`_

Parts Description
-----------------
When creating an active speaker, it will need power. For this project we have settled on a barrel styled :ref:`power plug <Power connector>`. These type of power supplies readable available are relatively inexpensive, but not any old power supply will do. There's are few requirements that is required to be met.
Please see the tables below for further details.

.. table:: Electrical requirements for the power brick

  +-------------+----------------+----------------+
  | Mains range | Output Voltage | Output Wattage |
  +=============+================+================+
  | 100V - 240V | 18V            | 60W            |
  +-------------+----------------+----------------+

.. table:: Physical requirements

  +--------------+-----------------+----------------+
  | Plug type    | Plug dimensions | Cable length   |
  +==============+=================+================+
  | Barrel, male | 5,5mm x 2,1mm   | >=1,5m         |
  +--------------+-----------------+----------------+

Sourcing requirements
---------------------
.. warning::

  When sourcing a power brick (power supply), it is really important that set power supply is `CE <https://europa.eu/youreurope/business/product-requirements/labels-markings/ce-marking/index_en.htm>`_ approved, as well as `RoHS <https://ec.europa.eu/environment/topics/waste-and-recycling/rohs-directive_en>`_ compliant. Therefore only approved power supplies must be used and supplied to the end customer.

Currently the only **approved** power supply is this one from Mean Well: `GST60A18-P1J <https://www.meanwell-web.com/en-gb/ac-dc-industrial-desktop-adaptor-output-18vdc-at-3-gst60a18--p1j>`_.

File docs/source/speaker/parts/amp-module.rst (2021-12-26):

Amplifier Module
****************

.. sidebar:: Parts information
  :subtitle: See the below for a quick overview of the naming and ID information of this part.

  | **Part name**: *Amplifier module*
  | **Parts ID**: 9X6S29

Part description
----------------
The amplifier module is a generally available, but custom, PCB design which are base upon the popular `Espressif ESP32 <https://www.espressif.com>`_ platform.

This is combined with an audio amplifier from Infineon. The `MA12040P <https://www.infineon.com/cms/en/product/power/class-d-audio-amplifier-ic/integrated-class-d-audio-amplifier-ics/ma12040p/>`_ is a strong candidate.

Sourcing
--------
.. todo:: sourcing of this module are still TBD.

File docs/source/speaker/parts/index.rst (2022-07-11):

Speaker parts
#############

.. toctree::
   :maxdepth: 1
   :glob:

   *

Generate a parts ID when adding a new part
==========================================

To generate a ID for a part, follow the below example. The following tool is used: `Short UUID <https://github.com/simplyhexagonal/short-unique-id>`_.

.. code-block:: bash

  suid -l 6 -d utils/uuid-dict.json

Please note that a simplified `dictionary <https://raw.githubusercontent.com/LydByDissing/stroem/main/utils/uuid-dict.json>`_ have been used to ensure only uppercase characters are used.

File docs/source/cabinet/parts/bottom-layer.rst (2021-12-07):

============
Bottom Layer
============

.. sidebar:: Parts information
  :subtitle: See the below table for a short naming and ID information of this part.

  | **Part name**: *Bottom layer*
  | **Parts ID**: WvQgn

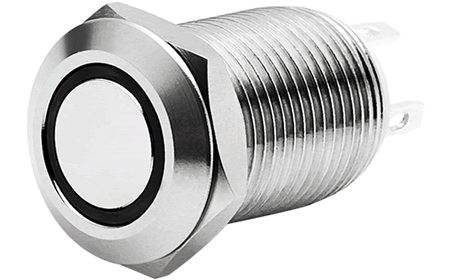
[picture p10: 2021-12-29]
docs/source/speaker/parts/push-button/12QBD21.gif

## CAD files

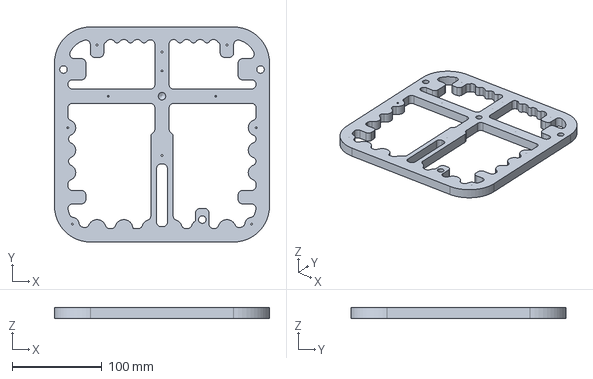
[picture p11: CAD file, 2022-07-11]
CAD/cabinet-layer-3.step
240.0 x 240.0 x 12.0 mm

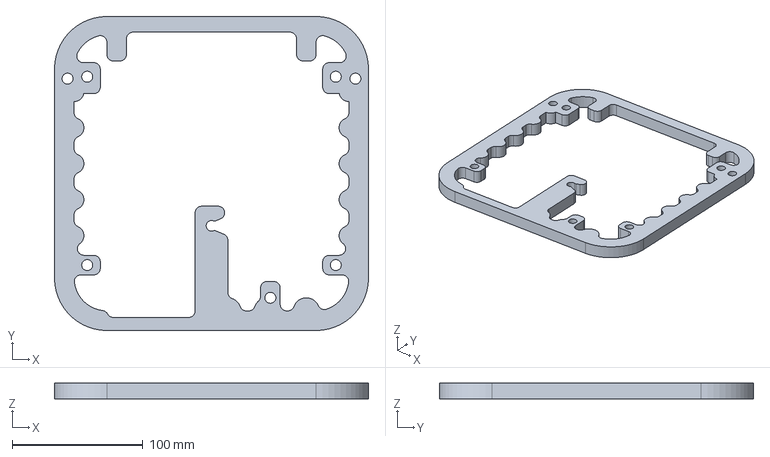
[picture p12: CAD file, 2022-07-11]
CAD/cabinet-layer-1.step
240.0 x 240.0 x 12.0 mm

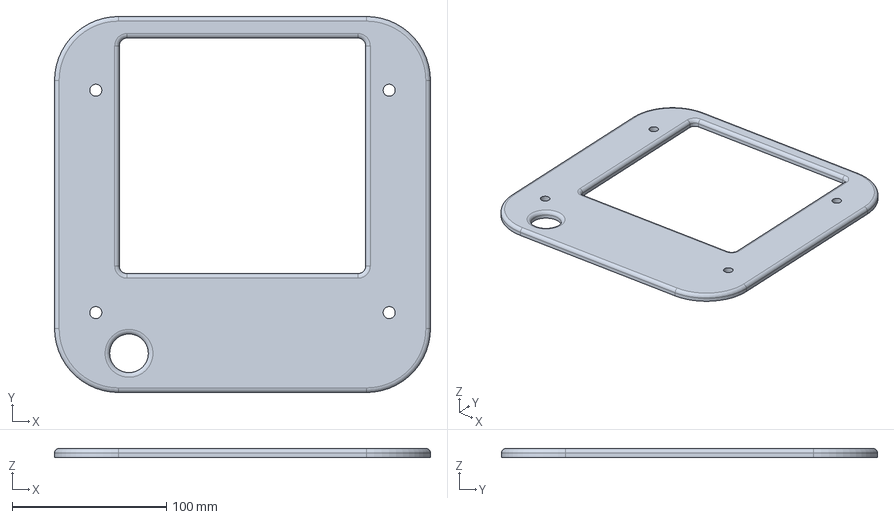
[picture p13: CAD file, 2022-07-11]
CAD/softtop.step
243.5 x 243.5 x 6.00 mm

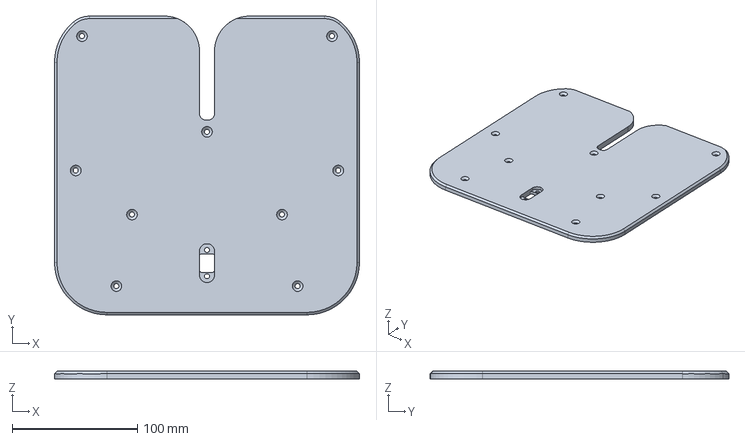
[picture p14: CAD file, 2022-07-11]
CAD/back-panel.step
244.0 x 239.0 x 6.00 mm

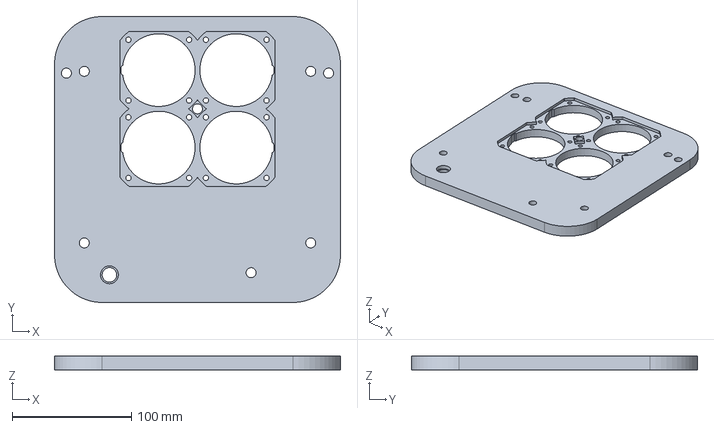
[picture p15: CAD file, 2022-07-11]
CAD/baffle.step
240.0 x 240.0 x 12.0 mm

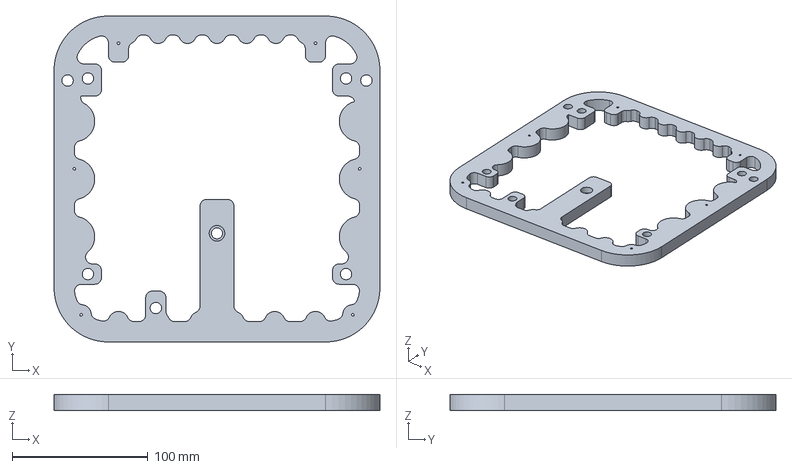
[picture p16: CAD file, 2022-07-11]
CAD/cabinet-layer-2.step
240.0 x 240.0 x 12.0 mm

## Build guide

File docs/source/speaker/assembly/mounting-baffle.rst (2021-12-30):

.. _mounting the baffle:

Mounting the baffle
*******************
The baffle and the main cabinet are now ready to be mated.

* `Baffle <cabinet baffle>`_
* `Main cabinet assembly <main cabinet assembly>`_

The baffle needs to be mated to the main cabinet. This is a relatively simply process, but first it needs to finished.

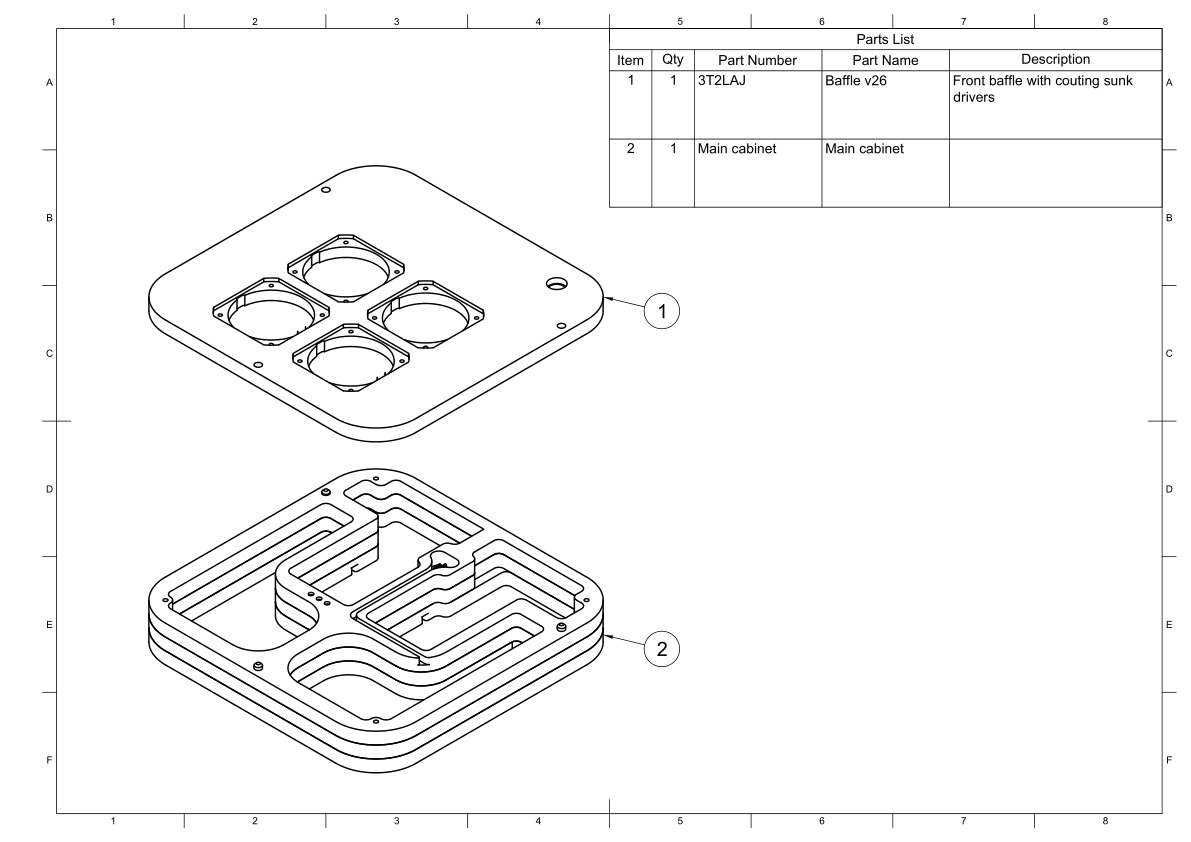
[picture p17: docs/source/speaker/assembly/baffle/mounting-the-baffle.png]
Exploded drawing of the main cabinet and the baffle


  Exploded view of all the parts needed to mount the baffle to the main cabinet.

Following the steps below to mount the baffle to the main cabinet.

1. Start by finishing the top of the baffle - see `parts description <cabinet baffle>`_ for additional details.

2. Add glue to the main cabinet and place the baffle on the main cabinet, using the dowels guide holes for proper placement.

  a. The top of the dowels should pertrude about 6mm out of the main cabinet. Enough to properly align the baffle on the cabinet.

3. Clamp down the parts while the glue sets.

Assembly video
--------------

To make it more clear how all these parts comes together, a short video showing an exploded view of the speaker can be found below.
This highlights how all the parts fit together with each other.

.. youtube:: 6zH1YJoNRr8

Downloads
---------

Download the drawing as a PDF :download:`mounting-the-baffle.pdf <baffle/mounting-the-baffle.pdf>`.

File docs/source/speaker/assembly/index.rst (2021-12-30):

  .. _Cabinet Assembly Description:

Cabinet Assembly
################

.. todo::

  Still missing these sections:

  4. linoleum
  5. drivers
  6. back panel
  7. soft top

.. toctree::
   :maxdepth: 1
   :glob:

   main-cabinet-assembly
   mounting-baffle

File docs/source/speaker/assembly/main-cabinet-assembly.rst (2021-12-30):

.. _main cabinet assembly:

Assembling the main cabinet
***************************

The main cabinet is assembled using the following 5 parts:

* `Cabinet Layer 1 <cabinet layer 1>`_
* `Cabinet Layer 2 <cabinet layer 2>`_
* `Cabinet Layer 3 <cabinet layer 3>`_
* `Dowels <dowels>`_
* `DC Power socket <Power connector>`_

Each of the three cabinet layers are glued together using standard indoor wood glue. To easily lineup the individual layers with each other, a set (3) of guide holes are bored in each layer. These are for the dowels.

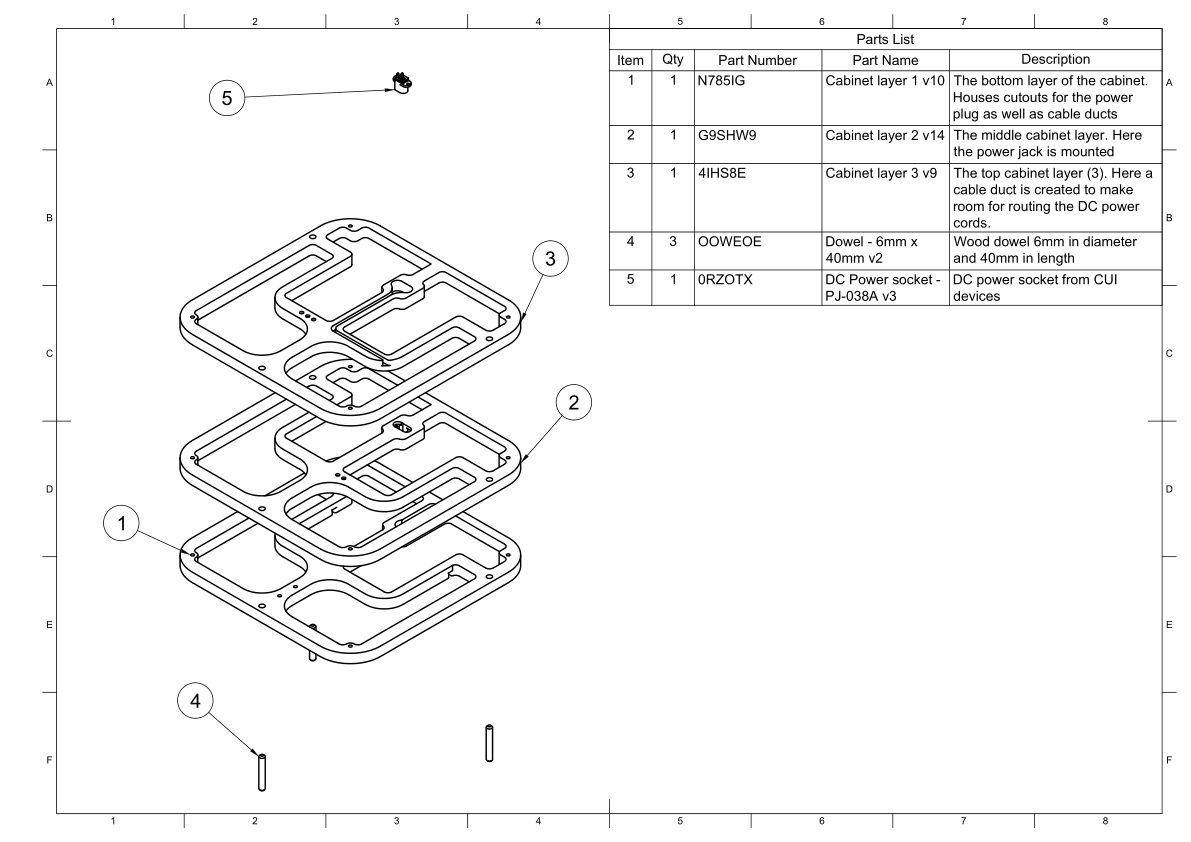
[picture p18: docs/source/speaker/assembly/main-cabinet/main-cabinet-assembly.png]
Exploded drawing of the main cabinet


  Exploded view of all the parts needed to assemble the main cabinet.

Following the steps below to assemble the main cabinet.

1. Start with layer 1 and place it, so the cable ducts and layer numbering faces downwards

2. Add wood glue to the guide holes and mount the dowels inside them. Make sure that go all the way through, but do not pertrude further than the face of this layer - otherwise the back panel can't be mounted correctly.

3. Now we are ready to add the second layer.

   a. Apply glue to layer 1 in order to the second layer to adhere to it.

   b. Now take layer two and ensure that the layer identification holes faces up.

   c. Add glue to the guiding holes and place it over the dowels and press down. Make sure to press the layer all the way down so it mates with layer 1.

4. The third layer can now be mounted. This is done in the same way as in point **3** above.

5. Clamp all the layers firmly together and let the glue set.

6. Finally we can mount the DC power socket. This is down with a couple of screw.

    a. Add some hot glue over the wires, to ensure they do not come off. We are encapsulating this socket inside the cabinet, so we do not want any faults.

    b. Place the wire harness in the cable duct and secure it with hut glue.

The main cabinet are now ready for the next stage: :ref:`mounting the baffle <mounting the baffle>`.

Assembly video
--------------

To make it more clear how all these parts comes together, a short video showing an exploded view of the speaker can be found below.
This highlights how all the parts fit together with each other.

.. youtube:: -KRVnBKZZOo

Downloads
---------

Download the drawing as a PDF :download:`main-cabinet-assembly.pdf <main-cabinet/main-cabinet-assembly.pdf>`.

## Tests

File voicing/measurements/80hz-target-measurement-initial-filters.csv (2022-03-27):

* Measurement data measured by REW V5.20.4
* Source: Umik-1 Gain: 12dB | MICROPHONE | L | volume: 1.000. Timing signal peak level -28.9 dBFS | measurement signal peak level -23.4 dBFS
* Format: 1M Log Swept Sine | 1 sweep at -10.0 dBFS using an acoustic timing reference
* Dated: Mar 25 | 2022 2:01:06 PM
* REW Settings:
* C-weighting compensation: Off
* Target level: 75.0 dB
* Note: Delay -0.0154 ms (-5.3 mm | -0.21 in) using estimated IR delay relative to Acoustic reference on L with no timing offset
* Measurement: 80Hz Target Mar 25
* Smoothing: Psychoacoustic
* Frequency Step: 0.36621097 Hz
* Start Frequency: 50.1709 Hz
*
* Freq(Hz) | SPL(dB) | Phase(degrees)
50.170898 | 60.907 | -69.4285
50.537109 | 61.222 | -70.3284
50.903320 | 61.534 | -71.2781
51.269531 | 61.843 | -72.2778
51.635742 | 62.148 | -73.3275
52.001953 | 62.451 | -74.4273
52.368164 | 62.749 | -75.5768
52.734375 | 63.044 | -76.7755
53.100586 | 63.336 | -78.0228
53.466797 | 63.625 | -79.3176
53.833008 | 63.910 | -80.6590
54.199219 | 64.192 | -82.0456
54.565430 | 64.470 | -83.4759
54.931641 | 64.745 | -84.9483
55.297852 | 65.017 | -86.4612
55.664063 | 65.286 | -88.0125
56.030274 | 65.552 | -89.6004
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

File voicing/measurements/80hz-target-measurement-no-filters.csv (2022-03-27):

* Measurement data measured by REW V5.20.4
* Source: Umik-1 Gain: 12dB | MICROPHONE | L | volume: 1.000. Timing signal peak level -17.3 dBFS | measurement signal peak level -8.3 dBFS
* Format: 1M Log Swept Sine | 1 sweep at -10.0 dBFS using an acoustic timing reference
* Dated: Mar 25 | 2022 9:53:45 AM
* REW Settings:
* C-weighting compensation: Off
* Target level: 75.0 dB
* Note: Delay -0.0204 ms (-7.0 mm | -0.28 in) using estimated IR delay relative to Acoustic reference on L with no timing offset
* Measurement: 80Hz Target Mar 25
* Smoothing: Psychoacoustic
* Frequency Step: 0.36621097 Hz
* Start Frequency: 50.1709 Hz
*
* Freq(Hz) | SPL(dB) | Phase(degrees)
50.170898 | 65.356 | 58.9540
50.537109 | 65.411 | 78.7382
50.903320 | 65.457 | 99.0684
51.269531 | 65.492 | 119.8679
51.635742 | 65.518 | 141.0543
52.001953 | 65.535 | 162.5400
52.368164 | 65.544 | -175.7660
52.734375 | 65.545 | -153.9574
53.100586 | 65.539 | -132.1289
53.466797 | 65.527 | -110.3751
53.833008 | 65.510 | -88.7889
54.199219 | 65.488 | -67.4604
54.565430 | 65.463 | -46.4756
54.931641 | 65.436 | -25.9153
55.297852 | 65.408 | -5.8542
55.664063 | 65.380 | 13.6402
56.030274 | 65.354 | 32.5078
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

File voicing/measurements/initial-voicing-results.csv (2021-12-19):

* Measurement data measured by REW V5.20.4
* Source: Dec 16 Filtered
* Format:
* Dated: Dec 18 | 2021 7:00:50 PM
* REW Settings:
* C-weighting compensation: Off
* Target level: 111.9 dB
* Note: ; Delay -0.0213 ms (-7.3 mm | -0.29 in) using estimated IR delay relative to Acoustic reference on L with no timing offset PK Fc 316.0 Hz Gain -12.30 dB Q 5.000 PK Fc 182.0 Hz Gain -9.00 dB Q 10.000
* Measurement: EQ Dec 16
* Smoothing: 1/3 octave
* Frequency Step: 0.3364563 Hz
* Start Frequency: 50.13199 Hz
*
* Freq(Hz) | SPL(dB) | Phase(degrees)
50.131989 | 117.472 | -159.2389
50.468445 | 117.525 | -160.9907
50.804901 | 117.457 | -158.7322
51.141357 | 117.355 | -155.4088
51.477814 | 117.220 | -151.1268
51.814270 | 117.056 | -146.0115
52.150726 | 116.863 | -140.1998
52.487183 | 116.644 | -133.8343
52.823639 | 116.400 | -127.0573
53.160095 | 116.134 | -120.0057
53.496552 | 115.847 | -112.8081
53.833008 | 115.542 | -105.5818
54.169464 | 115.219 | -98.4315
54.505920 | 114.881 | -91.4489
54.842377 | 114.529 | -84.7126
55.178833 | 114.164 | -78.2886
55.515289 | 113.788 | -72.2310
55.851746 | 113.402 | -66.5823
56.188202 | 113.007 | -61.3744
56.524658 | 112.603 | -56.6292
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

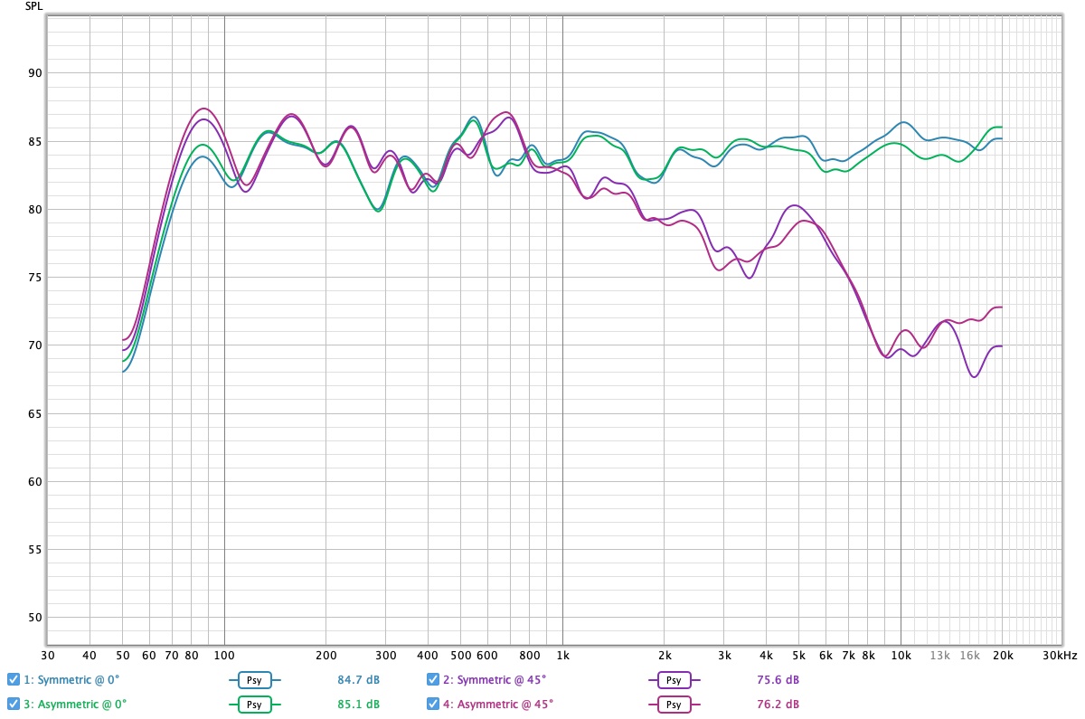
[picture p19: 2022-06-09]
voicing/measurements/shifted axis baffle/measurements.jpg

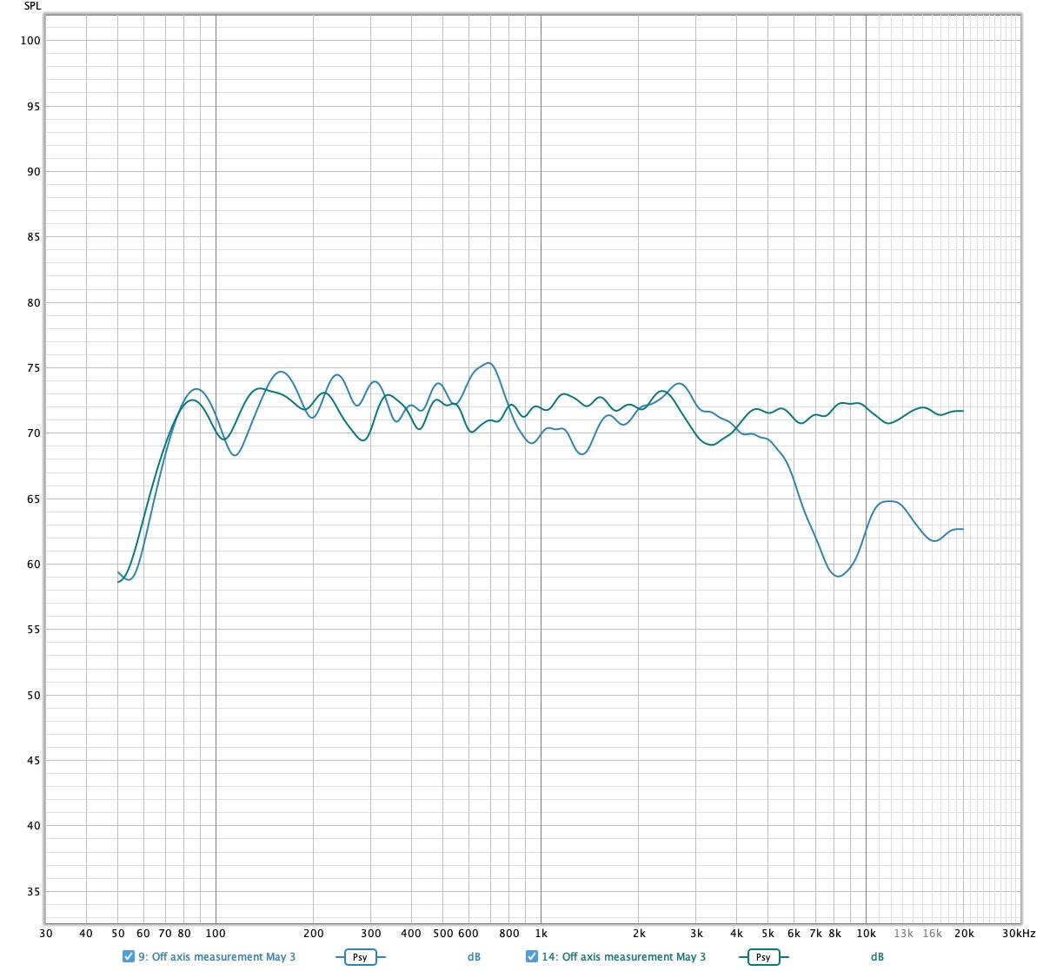
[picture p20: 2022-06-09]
voicing/measurements/shifted axis baffle/wider-dispersion.jpg

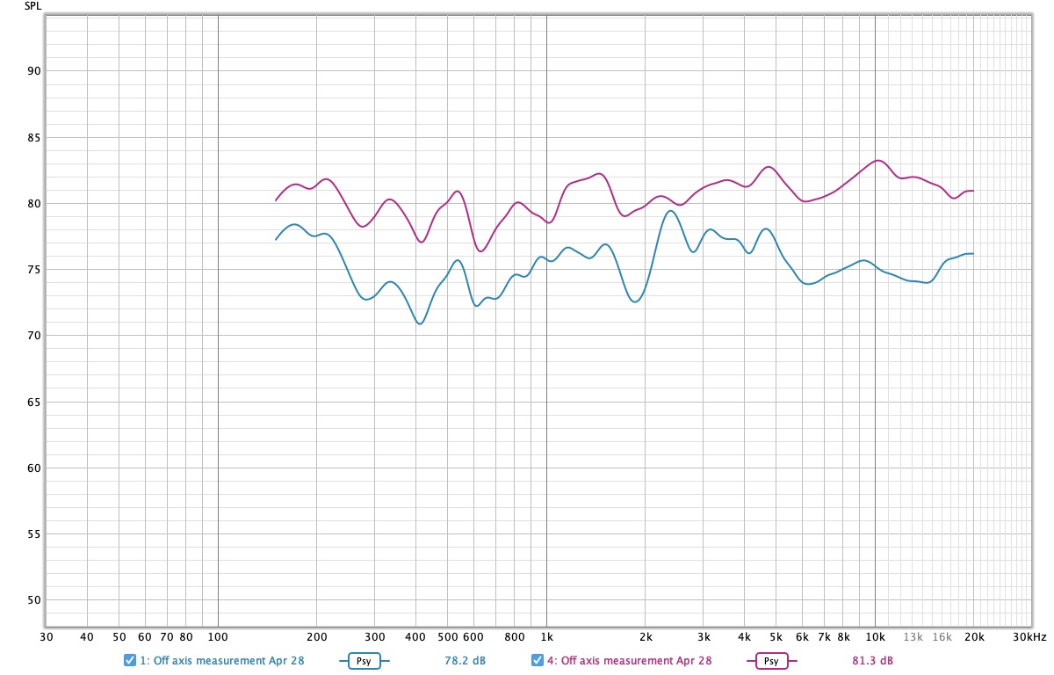
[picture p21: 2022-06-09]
voicing/measurements/shifted axis baffle/on-axis-measurement.jpg

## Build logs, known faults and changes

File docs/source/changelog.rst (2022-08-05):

Changelog
#########

.. changelog::
    :changelog-url: https://stroem.readthedocs.io/en/latest/changelog.html
    :github: https://github.com/LydByDissing/stroem/releases/

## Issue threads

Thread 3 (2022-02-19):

Finding optimal internal cabinet volume for best acoustic response from the drivers

TooDissing, 2022-02-19:
In order to make the most of the drivers, it is important to provide "enough" volume for each driver. But what is enough?
Each driver resides in its own internal cabinet - at least for now. This is done in order to minimize interference between the drivers, but does take up more room for bracing etc.

Finding the needed volume involves the following tasks:

- [ ] Build test cabinets with different volumes
- [ ] Measure each cabinet
- [ ] Validate possible frequency range and max SPL of each cabinet

The main goal are to keep the cabinet small, but at the same time ensure that the minimum requirements for frequency range and max SPL are met; find more information [here](https://wikifactory.com/+opennext/lydbydissing/files/Requirements).

emiltb, 2022-03-15:
I commented on the first blogpost, but wanted to elaborate a bit, because I think there are advantages to using a structured approach for optimization and testing of the prototypes. I believe that the suggested approach of simulating the acoustic properties is a good starting point (although I have no knowledge about that). However, many physical parameters come into play when testing the real acoustic performance of various prototypes, and the interactions between the various parameters can be difficult to discern.

### Dynamic Design of Experiments
The approach I suggest is called Dynamic Design of Experiments (DoE). In contrast to [Classical DoE](https://en.wikipedia.org/wiki/Design_of_experiments) where one sets up a factorial design and tests a predetermined number of combinations to create a model of a system, Dynamic DoE uses a Bayesian Optimization algorithm to model a system and incrementally learns about the systems performance based on its input parameters. This means that new iterations of the speaker design can be tested in iterations as small as 1, and new test parameters be determined on the basis of the newest findings.

Despite being a really advanced tool, it is freely available through [Brownie Bee](https://www.browniebee.dk/) in a publicly funded project. Danish Technological Institute recently published a brief video about on of their first case studies, describing the approach and results (https://www.youtube.com/watch?v=zHsTAhzvYYA). In this video a production company managed to optimize a production process with 20-30% of the experiments that they would normally have to perform.

### Suggested workflow
What Brownie Bee offers is a methodology to optimize the speaker design in (hopefully) as few iterations as possible. It would likely be achieveable by a workflow like this:

1. Determine the parameters of interest for the model through a brainstorming session. For input parameters this could be e.g. width, depth, height, materials, etc. as well as upper and lower bounds for these and output parameters would likely be frequency range, max SPL and response linearity.
2. Run simulations of the speaker design to get an idea of the effect of the parameter space.
3. Select three promising configurations based on simulations and construct prototypes. Measure the output parameters on the prototypes.
4. Input the input and output parameters of the first three experiments in Brownie Bee. This will then issue a new set of parameters in the area where it's model of speaker performance is most uncertain.
5. Construct a new prototype based on the suggestion from Brownie Bee and pass the output parameters back into Brownie Bee.
6. Repeat step 4 and 5 until satisfactory performance.

I would be happy to discuss this approach further and help in setting up the optimization algorithm.

TooDissing, 2022-03-16:
Thank you for the thorough walk through walkthrough and suggested workflow @emiltb.

Have you worked with this tool yourself?
It also seems like a big mouthful do endeavor into such a tool.

Maybe some practical examples would be great, or maybe you could assist with this tool when we get some data from the first cabinet?

emiltb, 2022-03-17:
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

I'll be happy to help. The tool is quite accessible once you get started, but I'm open to being actively involved once data is available. I'll post an example of how it could be used with some dummy data here as soon as I have time, just to give a better feeling of how it can be used.

emiltb, 2022-03-20:
I've run an optimization test using some dummy data I've created to illustrate the principle. The Python code used for my data generation is available in this Gist: https://gist.github.com/emiltb/a15c4db0598ab494a433ee138ca4bd76.

# Generating data for a hypothetical speaker
The Python code creates a `Speaker` class which takes three input variables: a (width, 15-30 cm), b (depth, 5-10 cm) m (material, either 1 or 2). Two response (sound pressure level (spl) and response linearity (lin)) variables are then created for the speaker based on these, which follow some equation to smoothly vary the response over the parameter space. In reality the input- and response variables of interest should be selected through a brainstorming session and discussions with someone with some level of subject matter expertise. It is possible to work with more input variables than this example, but if course it quickly increases the parameter space drastically.

The goal of the optimization is to approximate this equation for each response variable, so we can get an idea about how varying the input variables effects the response and use this to find an optimum.

If a hypothetical speaker is created with `prototype = Speaker(20, 8, 1)` it can be tested with `prototype.test()` which will output:
```
Speaker test results:
Speaker parameters: 20 cm x 20 cm x 8 cm, material 1
Sound pressure level: -74 dB
Linearity: +/- 3.5 dB
```
The reported spl is negative, because the optimization algorithm is set up to always minimize the response.

# Optimizing results
Brownie Bee is started and the input variables defined as shown in the picture below. It supports both continous, discrete and categorical values.

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

The only other parameter that needs to be set initially is Xi. It is on the same scale as our response (i.e. dB in our case). Initially it is best to start with a large value to make the algorithm more explorative. It can then be lowered later to optimize around the best results. For spl I started with Xi=30 and lowered it to 5 after 6 attempts.

In order to start the optimization in Brownie Bee, I need three initial measurements. @TooDissing has mentioned in several places that they are doing simulations to determine some properties of the speaker. I will assume that this work has been used to select three promising speaker configurations that have been created and has had spl and lin measured. These numbers are filled into Brownie Bee, and the algorithm run to select the next experiment.
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

I press Run, and then get the results of the first model estimation as well as a suggestion for the next prototype. If is is more practical to construct more speakers in one go, it is also possible to get suggestions for e.g. the next three prototypes:
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

I can then iterate over these steps, i.e. get a suggestion for the next experiment, and run the test in my `Speaker` class, until I am satisfied with the results. After 6 experiments I lowered Xi to 5 and then with 7 experiments I have these points:

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

And this response model, which shows the response dependence on each input variable as well as the interaction between pairwise input variables.
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

After 7 prototypes with SPL optimization I decided that I was satisfied with the results, and changed the input so all of the responses were the linearity meaurements instead. Assuming that all response variables of interest are measured for all prototypes, we can kickstart the new model by inputting already known data.
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

I kept iterating over linearity measurements until 20 prototypes had been "constructed" and tested.
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

We see, that we actually managed to find the lowest linearity value of 3.0 after 9 total prototypes, and that adding more measurements made the model more sophisticated.

### Comparing with the ground truth
Since this is all simulated data, I can provide insight into the "true" model behind our hypothetical speaker:

For sound pressure level:
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
For response linearity:
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

It turns out, that the optimization algorithm was able to find the global maximum for SPL in 7 attempts. It never found the true global minimum for response linearity in 20 tries, but came pretty close and found very low values in the parameter space given.

Let me hear what you think about this approach and what aspects you wish to discuss. I hope that this could be an interesting way of working, and think that it suits this project very well since the fabrication via CNC-routing makes it possible to quickly fine-tune and iterate over designs.

TooDissing, 2022-03-20:
@emiltb this looks really great! And there's a lot too digest as well :-)

Currently building a cabinet based on the most recent simulation that comes pretty close to the set design goals and will provide measurement data, when I have them available.

There's already some very well documented models for how the acoustics works and how the cabinet volume - in theory - affects the transfer function of the speaker output. But there's many more parameters that comes in play - many are fixed in this setup, but some can be tuned.

I started watching the webinar you linked above - it seems like a great approach - and will need to dig a little deeper into the subject, before I can start discussing the variable parameters and what to tune for with this approach.

Something that will impact the result a lot are the room as well as the speaker placement.

Will for sure look more into this, as this is a very cool approach. Let's see what is possible ans how we can benefit from it.

emiltb, 2022-03-26:
It's very interesting if knowledge from the existing models can be somehow be incorporated to design better experiments. I sent an e-mail last week to one of my former colleagues at Danish Technological Institute since I had some questions about the Brownie Bee app (mainly regarding producing one model with several input parameters and several output parameters, instead of having to creating a number of separate models as I illustrated above - long story short, it is implemented and possible to do). The BOOST Væksten project which is funded by The Danish Industry Foundation, is run by DTI with the goal of increasing the knowledge about the methodology and creating more cases illustrating how the tool can be used. This means that they are very interested in this project and are therefore very curious to hear more about it and discuss how it the tool could be used and how they might be able to help. They have asked for a meeting where it could be discussed - I'll definitely talk with them anyways, but I was wondering whether you @TooDissing would be interested in participating? It would be valuable to have someone with more knowledge about speaker design than me to put some perspective on the primary aspects of the optimization problem. Could you send me an email at emil@tbjerglund.dk if you are interested? Then we can set something up.

TooDissing, 2022-03-27:
First cabinet is now build with the tuning created for the 80Hz target. And just merged in the PR with all the updates to the design files.

Preliminary measurements and voicing have been performed and the sound is promising - yes I'm biased, but I feel that it does sound pretty decent 😎

TooDissing, 2022-05-03:
Started performing further simulations using the Brownie Bee app as an assistant. It is pretty hard to get the scores calculated correctly. More testing are needed to properly evaluate this tool.

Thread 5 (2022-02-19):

Best possible integration of the power plug in the cabinet

TooDissing, 2022-02-19:
### Description

When wall mounting the speaker it is important that the cabinet will be flush with the wall. This makes for a better sounding speaker as well as a more visually pleasing results.
Power needs are 18V at around 60W.

> **A word on USB-C with PD.**
> This is a create piece of tech and it is actually really attractive, but it also cost a lot. The charges and cables are expensive, especially when needing higher output like this speaker does.

For now we are looking at using a barrel plug. This is cheap, available and well proven.

How can we best integration a barrel socket into this cabinet and at the same time recess the barrel plug into the cabinet?
Can it be recessed in the back plate some how? How will this affect the overall depth of the cabinet?

It needs to be fairly easy to plug in, and it should not fall out, but at the same time avoid getting in the way for a fully flush mounted speaker.
It should also be possible to not wall mount the speaker, so this must be part of the consideration as well.

### Definition of Done

- [x] Barrel socket part selected
- [ ] Power adaptor with sufficient ampere and voltage selected
- [x] Socket well integrated into the cabinet and allows for both on wall mounting the speaker, and standing it on a shelf.
- [x] The depth of the cabinet is not impacted, or only slightly impacted, by the size of the socket, nor by the chosen integration method.

#### Documentation
All introduced and updated parts need to be documented/updated.
Any change to the assembly process should also be reflected in the updated documentation.

TooDissing, 2022-03-15:
Did a minimal mockup and test. Seems to be able to fit.
No CAD files in any shape to be checked in, but have a look [here](https://lydbydissing.autodesk360.com/g/projects/20211111465720931/data/dXJuOmFkc2sud2lwcHJvZDpmcy5mb2xkZXI6Y28uVFk1RE5taVpSSkdUUUdGRzRlSkdLQQ/dXJuOmFkc2sud2lwcHJvZDp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) if interest.

TooDissing, 2022-03-15:
also need to look into whether or not a sufficient power supply exists with the correct barrel dimensions.

Closed 2022-04-06.

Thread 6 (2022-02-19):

Initial voicing of the speaker - prior to PCB

TooDissing, 2022-02-19:
### Description

When creating a speaker it is important to properly voice the speaker, so it performs well acoustically. The same goes for this speaker.
This is an active speaker and all acoustical tuning occurs in the digital domain using "DSP logic", but implemented in in software. This will introduce a small processing delay, but it will dramatically decrease PCB development cost.

Before the final hardware platform is ready, only the initial tuning is possibe, but it is still very important not to apply filter-logic which isn't possible on the final HW platform.

The DSP filter constraints are:
* Filter banks of biquads
* Stereo channels can be EQ'ed individually
* Direct correlation between number of filters and the processing delay they introduce

The purpose of the voicing are to fulfill the listed design goals as well as creating a tuning that doesn't damage any components over time and one that sounds well.

The result of the voicing process will be a set of filters to adjust the output to match the desired acoustic goals.

### Definition of Done

- [x] Frequency response are linear within the required frequency range within ±4dB
- [x] High speech intelligibility
- [x] Definition of the needed DSP filters

#### Documentation
The filters needed to adjust the output should each be documented so it is clear why they are implemented the way they are. This will make it easier to understand and maintain down the line.

TooDissing, 2022-02-19:
The DSP will be implemented in software on the ESP32 module. This will mean that each each filter will introduce a small delay, but as described above this isn't a real world problem. At least not yet :-)

For the development setup I am currently using [HEnquist/camilladsp](https://github.com/HEnquist/camilladsp) on a laptop.
Then I can "just" use a normal amp - handy as the amp board etc. isn't ready at this stage.

The current state of the filtering can be found in [voicing-dsp-filters.yaml](https://github.com/LydByDissing/stroem/blob/f080fef9bd6ae4da4cfc40e10fc8d8a278fbc75d/voicing/voicing-dsp-filters.yaml).

IsaackRasmussen, 2022-02-19:
Just out of curiosity, but is the ESP32 powerful enough for CamillaDSP? I only looked superficially according to their details, a Rasperberry PI 4 which should be much faster than a ESP32 is still 55% loaded, processing CamillaDSP with a certain set of filters.

ESP32 is definitely convenient with multi-cores, wifi and bluetooth builtin.

TooDissing, 2022-02-20:
> Just out of curiosity, but is the ESP32 powerful enough for CamillaDSP? I only looked superficially and according to their details, a Rasperberry PI 4 which should be much faster than a ESP32 is still 55% loaded, processing CamillaDSP with a certain set of filters.
>
> ESP32 is definitely convenient with multi-cores, wifi and bluetooth builtin and already certified.

I am pretty sure it will struggle a lot and this is also not the intension. We will not use Camilla DSP on the ESP32 board. Here the filtering will be implemented in software - written in C.
We have done a proof of concept on this, as this works great. As mentioned all filters will add a delay, but for audio playback this isn't a real world problem.

I hope that the above make sense :-)

IIMunchII, 2022-02-20:
For sure for audio playback latency on filters is not an issue. My initial question on this subject was related to interfacing for the filter settings as a feature in the final product. I understand now this is out of scope of the project so let’s focus on implementing the filters 😊

TooDissing, 2022-02-20:
It could be interesting with an option to load various filter configurations on demand, but unsure what it will require at this stage

TooDissing, 2022-04-06:
The latest version of https://github.com/LydByDissing/stroem/blob/main/voicing/voicing-80hz-target.yaml sounds so well that I considered the initial voicing for a succes

Closed 2022-04-06.

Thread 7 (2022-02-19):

Local manufacturing

TooDissing, 2022-02-19:
### Description

_This will be an exploratory task, as this is uncharted territory._

One of the main goals of this project, besides creating a wifi speaker, are to validate the **local manufactoring** concept. This concept both need to be validated here in Denmark (we reside in Copenhagen, Denmark), but also in more distant places like Chile or Dubai for instans.

We need to figure out how best to enable local production/fabrication of this speaker.
The idea are to first look at doing this locally (greater Copenhagen area in Denmark) for easy support and quick turn around time on changes, then perform more remote tests of the process (future task).

Currently the following questions needs answering:

1. How should ready made parts be source at different locations?
    1. Parts like barrel socket, botton, drivers and PCB
2. Quality Assurence on fabricated speakers
    1. Material quality
    2. How can we ensure that the fabricated product meets the required quality?
    3. How to ensure that the speaker measures correctly; within which margins?
3. Customization based on available materials
    1. Like availability of different types of cloth and linoleum

### Definition of Done

- [ ] Economic feasibility of this manufactoring process is understood
- [ ] First locally (same country) manufactured speaker are produced

#### Documentation
Which part of the documentation needs to be updated or extended?

TooDissing, 2022-02-19:
Some European makers that maybe could be of interest: https://www.opendesk.cc/open-making/makers

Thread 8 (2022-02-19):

Description of the speaker assembly process

TooDissing, 2022-02-19:
### Description

A detailed textual description of how one can produce/assemble this speaker.

This will be a highly iterative process as all parts and steps isn't finalized at the time of writing.
The assembly documentation can be found in its latest form at the [cabinet assembly section](https://stroem.readthedocs.io/en/latest/speaker/assembly/index.html) of the documentation.

### Definition of Done

- [ ] All parts have been documented
- [ ] all the assembly steps have been documented
- [ ] any special assembly steps are accommodated by appropriate assembly video or additional documentation and media
- [ ] it should be possible to fully assembly the speaker by following the combined documented process

#### Documentation
All parts must be documents as well as all sub assemblies and their final assembly. This goes for the cabinet, PCB and driver mounting, wires etc.

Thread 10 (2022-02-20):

Sustainable cabinet material and use

TooDissing, 2022-02-20:
### Description

With the Strøm project we want to make a reasonably sustainable speaker cabinet. This starts by selecting sustainably sourced materials, but material use is equally important.

When looking at sustainability the three R's are important: Reduce, Reuse and Recycle.
It can be hard to equally accommodate for all of these three factors, but with this task we need to figure out what is possible.

The speaker cabinet construction is designed to be manufactured from the following materials:
* Linoleum (the cabinet is wrapped in linoleum)
* Wood based boards, like MDF or multiplex
* Dowels
* Wood glue
* Paint

Most of these materials are sustainable on their own, but how does it look when combining these materials into a manufactured speaker cabinet?
MDF can't be recycled, but how does its environmental impact compare to a material like multiplex (plywood)?
How much does the expected lifetime of the product impact the environmental "cost" of a certain material?

When combining/lining a board material with linoleum it is now harder to recycle these materials individually. At least without proper separation.
It is unlikely that it will be possible to line a board material with linoleum in a way, that makes it possible to easily separate when the product is end of life; i.e full product disassembly. But if it is possible please share how :-)

More investigation are needed in order to validate different materials against each other.
A few materials that could be of interest:
* MDF
  - Usually made from cutoffs and other wood waste
  - Cheap
  - Easy to work with
* Multiplex
   - Higher grade material than MDF
   - Is recyclable
   - Easy to work with

More suggestions are welcome.

### Definition of Done
- [] the main cabinet material have been chosen

#### Documentation
The documentation of each part must be written or updated

TooDissing, 2022-02-21:
it is worth noting that MDF does, to some extend, off gas some formaldehyde: https://echa.europa.eu/documents/10162/cc0acabf-6e82-f2ed-5dbe-8058f48ce6c4.
Can/should/must this be controlled or mitigated in some way?

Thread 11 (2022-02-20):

Dynamically load different - and custom - filter configurations

TooDissing, 2022-02-20:
### Problem
With the current design, the filter (DSP) configuration of h

**Describe the solution you'd like**
A clear and concise description of what you want to happen.

**Describe alternatives you've considered**
A clear and concise description of any alternative solutions or features you've considered.

**Additional context**
Add any other context or screenshots about the feature request here.

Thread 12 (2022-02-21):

Attaching fabric to the soft top

TooDissing, 2022-02-21:
### Description

The speaker front, where the drivers are mounted – i.e. the baffle – must be covered by fabric. This is done to solve two things:
1. to cover up the drivers as not everyone share the same visual appeal for speaker drivers
2. to visually "finish" the cabinet as this helps to close the "open" linoleum side

The fabric or cloth are to be mounted to a frame. This frame we call a [soft top](https://stroem.readthedocs.io/en/latest/speaker/parts/softtop-frame.html).

It must be fairly simply to remove the fabric for cleaning, repair or replacement. So gluing doesn't seem to be an option.

### Definition of Done

- [ ] Cloth can be attached to the soft top
- [ ] The cloth is flush with the sides of the cabinet
- [ ] doesn't touch drivers when playing (at no volume)
- [ ] the cloth is removable without damaging it and can be reattached

#### Documentation
The soft top frame and cloth parts description must be updated as well as the assembly process.

TooDissing, 2022-02-24:
If we create a type of "speaker sock" that fits over the soft top frame, then it might make sense to create a groove on the back of this frame to catch all the "overhang" as well as the stitching.
There should be plenty of room as the drivers aren't placed all that close to the sides.

Then we can maybe even avoid adding an elastic band inside the needed fold?

MarcAlHauToe, 2022-03-10:
How about making the speaker so that it accepts all kinds of fabric as its softcover?

This way the user, or his wife, is able to customize the look of the speaker by swapping the softcover with any style of fabric of their own choosing.

You could add a cutting template for the fabric, as a help to the buyer, so it is easy to cut new softcover.

This could greatly increase the WAF of the speaker.

TooDissing, 2022-03-10:
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

That is a pretty good idea - to even further enable customization for the look and feel.
We are still considering how to best mount the fabric, but we for sure needs to make it easy to replace it. Either to change the colors or just to clean it.
We will for sure also make any developed template available as part of this project.

albjerre, 2022-03-10:
Does it have to be fabric?
What about a thin wooden cover with laser cut perforations in it? Or a thin 3D printed perforated plastic cover made with plant based PLA plastic?

TooDissing, 2022-03-10:
> Does it have to be fabric?
> What about a thin wooden cover with laser cut perforations in it? Or a thin 3D printed perforated plastic cover made with plant based PLA plastic?

Fabric seems to the be easier option, as it require less post processing that 3D print, but as we will be using a simple snap-on mounting system for the soft top, customizations are possible :-)

And for the perforated wood I think that it will be hard to make it in such a way, that these perforations only have limited impact on the acoustics.
I have seen these perforated wood panels used in acoustic panels, which helps limit/diffuse the airflow.

albjerre, 2022-03-10:
> Fabric seems to the be easier option, as it require less post processing that 3D print, but as we will be using a simple snap-on mounting system for the soft top, customizations are possible :-)
>
I could try to make a test with a
3D printed cover using the same holes size as on a Sonos One speaker. I don't necessarily think it will require post processing.

TooDissing, 2022-03-10:
> > Fabric seems to the be easier option, as it require less post processing that 3D print, but as we will be using a simple snap-on mounting system for the soft top, customizations are possible :-)
>
> I could try to make a test with a 3D printed cover using the same holes size as on a Sonos One speaker. I don't necessarily think it will require post processing.

That would be cool! We are planning on using these snap fasteners: https://www.monacor.dk/produkter/kabinet-tilbehoer/vnr/124250/. The female one will be mounted in the baffle.
I'd better add the to the list of parts.

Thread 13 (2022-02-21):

Maturing of the cabinet production method and process [DRAFT]

TooDissing, 2022-02-21:
### Description

One of the goals of this project are to be able to produce this speaker in a "standard" fablab, maker space or a small CNC shop. This is because we, with this project, would like to enable local manufactoring. The chosen materials and manufacturing process must therefore be feasible in this setting.

The production process must be described in the projects documentation, basically making it a **Production Requirements Document** (PRD).
This description are done under the following assumptions:
* Small scale production run
* Makers are not trained cabinet/wood workers
* Most parts will be cut on a CNC aided router table
* Non fabricated parts and materials can be source with relative ease

### Definition of Done

- [ ] All needed parts of the speaker and their production can be easily source by small businesses and individuals
- [ ] Clear and concise assembly description

#### Documentation
Which part of the documentation needs to be updated or extended?

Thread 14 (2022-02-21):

Finding sustainable acoustic cabinet fill

TooDissing, 2022-02-21:
### Description

When building a speaker cabinet it is important to limit any cabinet resonnances introduced by the drivers. This is mainly done by creating a sturdy cabinet and filling it with various acoustic foam materials. These work great, but are often oil based and not the most sustainable product available.

This is a small and sturdy cabinet, but there will likely be a need for some kind of damping.
In the "old days" wool (yes from sheep) where used.

Within this task we need to source and test various sustainable alternatives to the modern "poly fill" material.
Material goals:
* Sustainable
   * How does different products compare with each other an to no fill
   * and what about wool?
* Sourcing should be relatively easy - and possible for small businesses as well as individuals
* A material should improve the acoustical performance of the overall speaker compared to a cabinet without acoustic fill

### Definition of Done

- [ ] Wool and other compatible materials have been tested and compared
- [ ] the selected material must be significantly better than no fill

#### Documentation
List of parts must be updated and the construction process as well.

TooDissing, 2022-02-21:
We have seen good results with this type of material: https://www.visaton.de/en/products/accessories/cabinet-construction-accessories/damping-material

TooDissing, 2022-02-21:
Maybe this stuff could make sense: https://www.kvadrat.dk/en/really/products2/acoustic-textile-felt-fr

TooDissing, 2022-04-17:
Have tested with wool filling in the latest version of the cabinet and it seems to perform well.

More tests need to be carried out (and other materials), should preferably be performed before we can close this issue.

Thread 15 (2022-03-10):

Adding snap fastener part to the parts list

TooDissing, 2022-03-10:
> > Fabric seems to the be easier option, as it require less post processing that 3D print, but as we will be using a simple snap-on mounting system for the soft top, customizations are possible :-)
>
> I could try to make a test with a 3D printed cover using the same holes size as on a Sonos One speaker. I don't necessarily think it will require post processing.

That would be cool! We are planning on using these snap fasteners: https://www.monacor.dk/produkter/kabinet-tilbehoer/vnr/124250/. The female one will be mounted in the baffle.
I'd better add the to the list of parts.

_Originally posted by @TooDissing in https://github.com/LydByDissing/stroem/issues/12#issuecomment-1064403020_

TooDissing, 2022-04-17:
This is likely going to be irrelevant as I am looking at screwing the soft top on to the baffle. This avoids gluing these plastic studs to the baffle and the soft top; which will be hard to remove, repair or replace. A simple euro screw seems to be a more reliable choice and should make it easier to repair.

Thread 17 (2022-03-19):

AirPlay not app?

sevhyg, 2022-03-19:
**Is your feature request related to a problem? Please describe.**
More convenient or smooth connectivity with Apple devices.

**Describe the solution you'd like**
AirPlay 2 support.

**Describe alternatives you've considered**
I think the most relevant alternatives seems to be scoped already - Bluetooth and Spotify Connect.

**Additional context**
Just curious about this. Guess the reason for not including AirPlay is due to it being a proprietary technology with licene fees? According to https://mfi.apple.com/en/faqs.html the cost seem inexpensive (99 USD/year), but still conflicts with the open source aprroach - and guess it might not even be the actual amount it would costs.

TooDissing, 2022-03-20:
I haven't actually looked into this much, but the fee doesn't seem to be the blocker.

However I haven't seen an open source implementation of this for the ESP32 platform. There seems to be a number of implementation in Python and Go (and I am sure others): https://github.com/openairplay/goplay2.

It could be an interesting addition for sure.

Deltini, 2022-03-30:
It appears that AirPlay is at least planned as a plug-in in the euphonium software.

https://github.com/feelfreelinux/euphonium/blob/master/docs/plugins.md#planned-plugins

But as of now, no code has been committed.

TooDissing, 2022-04-05:
yeah, no code yet. But for sure a desirable feature.

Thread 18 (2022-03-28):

The industrial design looks very generic

KalleNor, 2022-03-28:
The ID of the speaker looks generic and very close to the design of the Braun LE03 speaker.
https://braun-audio.com/en-GLOBAL/audio-hifi/speakers/wireless-speakers/le03/p/156109

I suggest to start an exploration phase of different design possibilities, that would make the speaker stand out in the market.

Once a minimalistic yet unique design has been defined, then start doing user tests.

TooDissing, 2022-03-28:
Thank you for the enhancement and for the link to the Braun speaker and for the input.

True enough. The design of the cabinet isn't revolutionary and it has likely been made many times over.
Here's an example from IKEA: https://www.ikea.com/jp/en/p/eneby-bluetooth-speaker-black-gen-2-90492423/

There's also an old design icon, but can't find the link right now, of a similar sized and shaped speaker with built-in CD player.

@KalleNor It sounds like you have experience within this field. Maybe you could share some pointers on how to best approach this?

TooDissing, 2022-03-28:
> There's also an old design icon, but can't find the link right now, of a similar sized and shaped speaker with built-in CD player.

Found it.

It seems [they](https://www.muji.com) did a revamp (in 2020) of the original - which I didn't know of beforehand - and the STRØM speaker looks a lot closer to that I must admit.

https://www.fastcompany.com/1672146/mujis-iconic-cd-player-redesigned-for-the-mp3-age

Here's an image:
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

KalleNor, 2022-03-29:
I do have a lot of experience within design of speakers as former Concept & Design manager from B&O.
My home page is www.nordbodesign.dk

You are right about the resembles of the Strøm speaker and the Muji speaker/CD player - The Strøm speaker should have a design of its own.
The good part about a minimalistic, iconic & timeless design is it will not be discarded by a passing trend rather be the  obvious choice for upgradability to last for a long time. Often in this case, quality of materials and an emotional value attached to the design plays a roll of how long you like to keep the product.

I am not saying the Strøm speaker should be very expensive but just something to have in mind.

What I would recommend is to look at the competitor landscape, see where the Strøm speaker would make a difference. Make sure the use case is right - I might be an idea to change the requirement of "wall mounted" also to include "free standing" because many people don't even bother about putting screws in the wall or live in a flat were they are not allowed to put things on the wall.
Emphasize the sustainable materials in the design.

TooDissing, 2022-03-29:
Thank you for the input @KalleNor. The speaker are also intended for a *none wall mounted scenario*, as I completely agree with you. Many people do not bother to mount it on their wall. So that use cause must also be supported.

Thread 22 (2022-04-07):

Google cast on esp32 exists!

jakob1379, 2022-04-07:
In regards to the connectivity and casting of audio via wifi I'd suggest having a look at this repo which managed to implement the Google cast protocol on esp32

https://github.com/sle118/squeezelite-esp32

TooDissing, 2022-04-08:
Thank you for the link @jakob1379. Always great with an implementation reference.

rektide, 2025-04-06:
There is also the open standard [Open Screen Protocol](https://github.com/w3c/openscreenprotocol) that was created as an open protocol to enable implemtations of Web Presentation API. This was sort of Google being compelled to make a backend like Chromecast, but public, for adding Presentation API to the web.

Either OSP or Chromecast would be lovely. It feels like a huge ask, if done fully really does mean having a browser running on the device effectively, but enables so so much. Sparks my joy.

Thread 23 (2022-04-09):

Implement True Wireless Stereo (TWS)

TooDissing, 2022-04-09:
The current scope for STRØM 1.0 are mono playback only. For an enhanced listening experience stereo playback should be possible.

**Describe the solution you'd like**
It should be possible to support stereo playback using two STRØM speakers. This feature should be implemented using a wireless connection.

The main problem are how to synchronize the clock of the two speakers, as this is required in order to minimize any delay between the playback from each speaker.

The "classic" TWS implementation in Bluetooth can't be used here, as this will require a proprietary Bluetooth chip and software stack. This is not part of the µVox hardware platform.

There seems to have been done some serious research within this area, which are worth looking further into. The following research promise a clock drift across multiple devices of under 1µs. That must be more than enough for this use case.

In the below paper two interesting concepts are mentioned: X-Sync and X-Burst.
[Poster: Accurate Cross-Technology Clock Synchronization Among Off-the-Shelf Wireless Devices](https://www.ewsn.org/file-repository/ewsn2020/162_163_grubmair.pdf?attredirects=0%26d=1)

**Describe alternatives you've considered**
A wired connection is possible, but isn't really considered as a solution.

TooDissing, 2022-04-20:
I had a short talk with the researcher behind the above study and it seems that the X-Sync / X-Burst isn't the most ideal solution for this application. Their main focus are on syncing devices using different network stacks; i.e. mixing Bluetooth and Wifi.

A few suggestions on a different approach:
* take a further look into BLE Audio, to see if we can rely on its clock sync mechanism. Not using BLE for the audio transfer, but solely for synchronization of the device clocks
   * Some work are done to utilize this feature within the open source community
* TI have created some proprietary logic for this: https://www.ti.com/lit/an/swaa162a/swaa162a.pdf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
   * looks like it will be hard to implement this in the µVox platform as it requires various pre-build BIN's

TooDissing, 2022-04-22:
another great paper about this topic: https://www.usenix.org/system/files/atc21-chen.pdf

TooDissing, 2022-05-11:
Maybe also of relevans? https://gitlab.com/painlessMesh/painlessMesh

TooDissing, 2022-05-11:
An ESP32 FTM example: https://github.com/espressif/esp-idf/blob/a82e6e63d9/examples/wifi/ftm/README.md

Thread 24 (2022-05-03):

Restructuring of the documentation

TooDissing, 2022-05-03:
### Description

The documentation isn't following any specific format or template and therefore lacks a bit of structure. With this issue we would like to learn against existing documentation templates such as https://github.com/OPEN-NEXT/WP2.3-Guideline-and-template-for-documentation-of-OSH-design-reuse. Not all sections are relevant for this project, nor at this stage of development.

We will use what is suitable.

### Definition of Done

- [x] Scaffolding for the new structure in place
- [x] There's a section to cover must, if not all, aspects of the product life cycle

Closed 2022-07-11.

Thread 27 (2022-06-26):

Support for external control - i.e. remote control support

TooDissing, 2022-06-26:
**Is your feature request related to a problem? Please describe.**
When performing normal playback it is sometimes cumbersome to reach for the phone, table or other playback device to change the track or the volume. It would be great to have support for various remote control capabilities.

**Describe the solution you'd like**
Possible to connect with various bluetooth based remote controls.

**Describe alternatives you've considered**
The alternative are physical buttons

**Additional context**
Add any other context or screenshots about the feature request here.

TooDissing, 2022-06-26:
Something like this *instructable* could be very relevant: https://www.instructables.com/ESP32-Bluetooth-BLE-Remote-Control/

TooDissing, 2022-06-26:
https://github.com/happycodelucky/ortho-remote-node

TooDissing, 2022-06-26:
https://www.arduino.cc/reference/en/libraries/esp32-ble-midi/

TooDissing, 2022-06-26:
https://randomnerdtutorials.com/esp32-ble-server-client/

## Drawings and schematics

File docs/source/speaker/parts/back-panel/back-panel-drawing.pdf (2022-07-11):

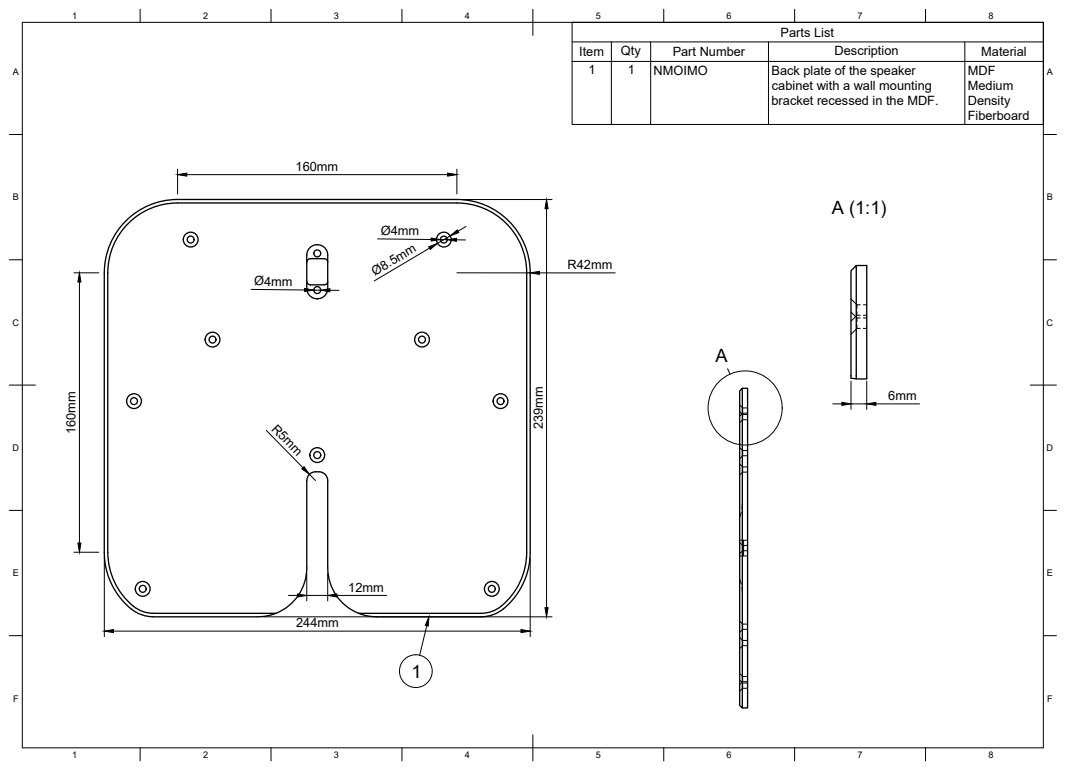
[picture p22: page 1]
Parts List

Item | Qty | Part Number | Description | Material
1 | 1 | NMOIMO | Back plate of the speaker cabinet with a wall mounting bracket recessed in the MDF. | MDF Medium Density Fiberboard

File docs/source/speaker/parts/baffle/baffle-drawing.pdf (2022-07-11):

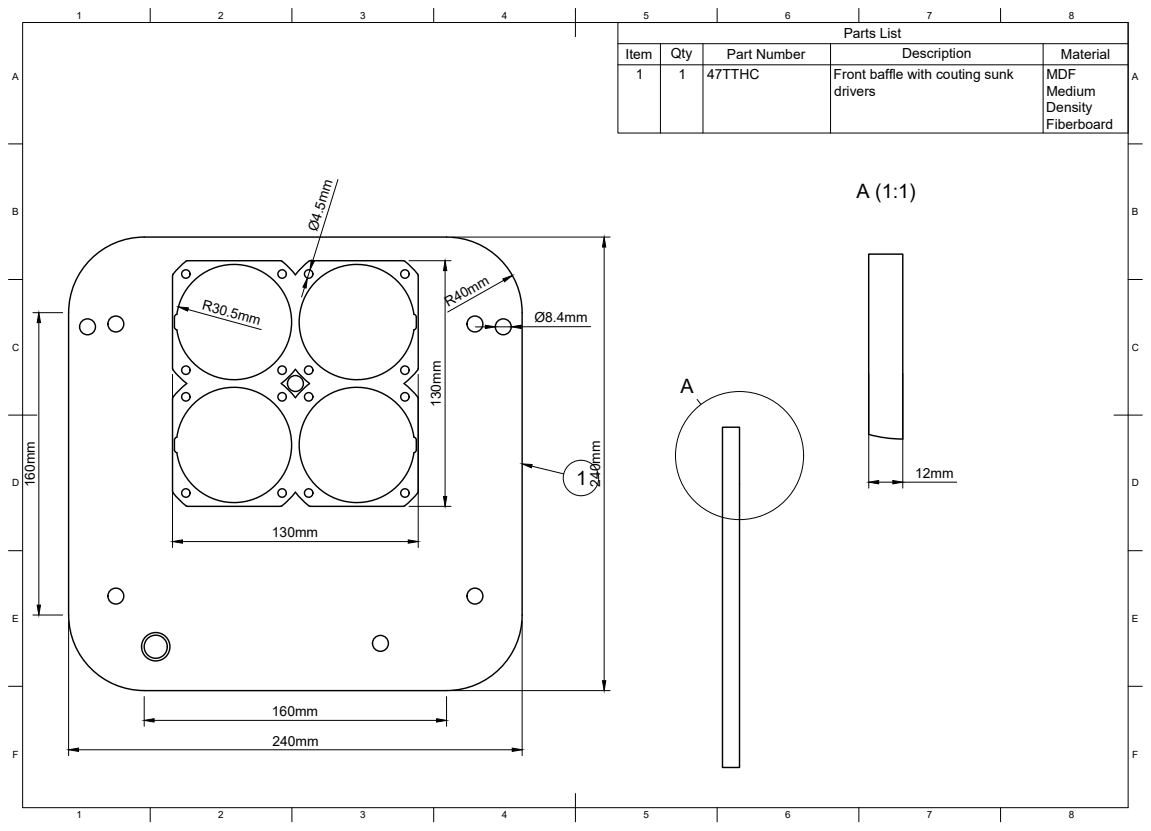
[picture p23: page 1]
Parts List

Item | Qty | Part Number | Description | Material
1 | 1 | 47TTHC | Front baffle with couting sunk drivers | MDF Medium Density Fiberboard

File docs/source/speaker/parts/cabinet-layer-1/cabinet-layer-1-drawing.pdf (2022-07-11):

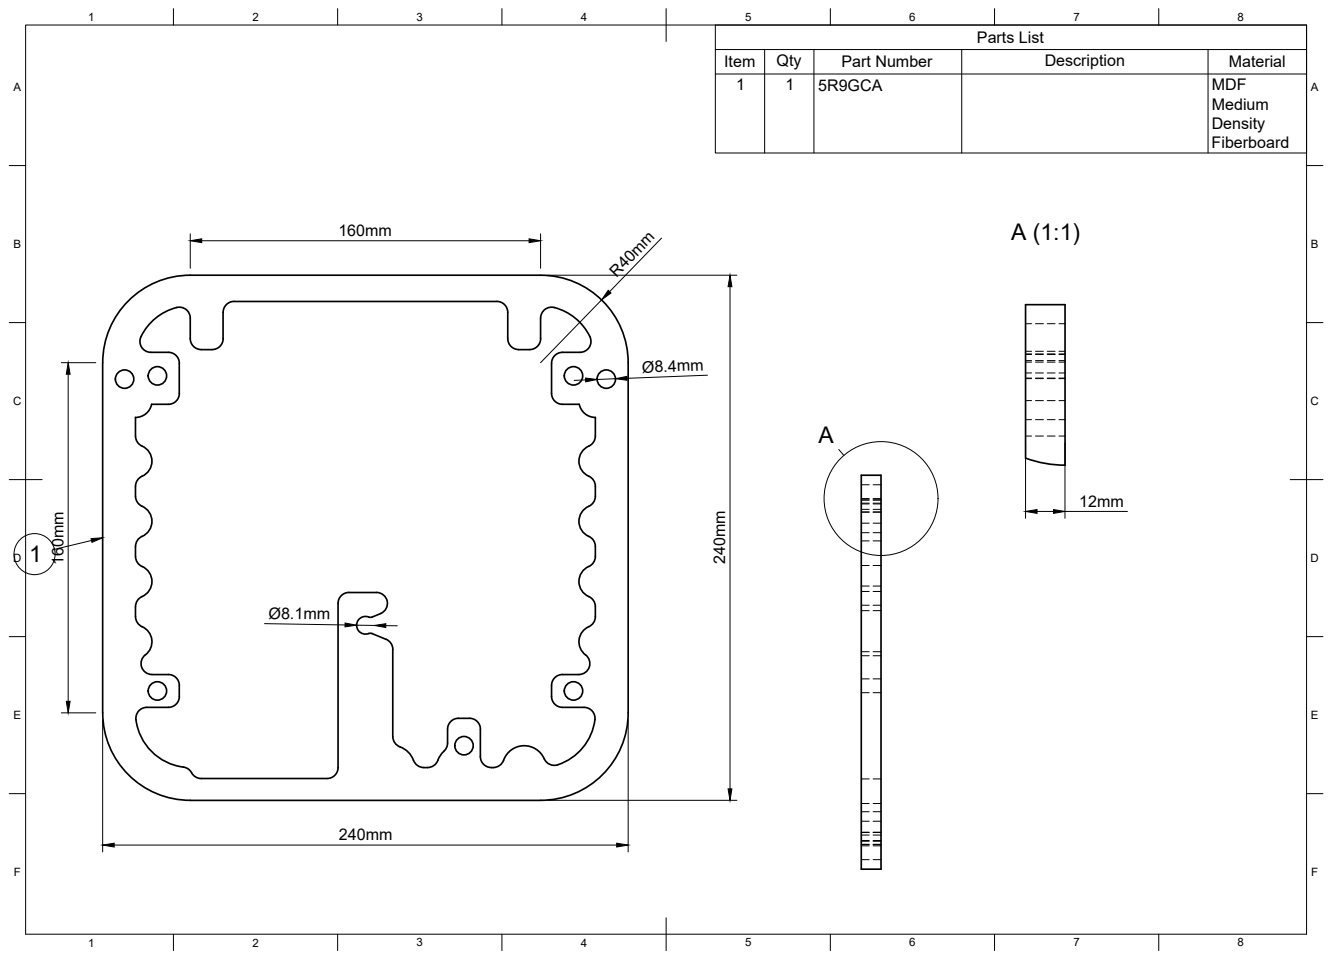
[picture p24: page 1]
Parts List

Item | Qty | Part Number | Description | Material
1 | 1 | 5R9GCA | | MDF Medium Density Fiberboard

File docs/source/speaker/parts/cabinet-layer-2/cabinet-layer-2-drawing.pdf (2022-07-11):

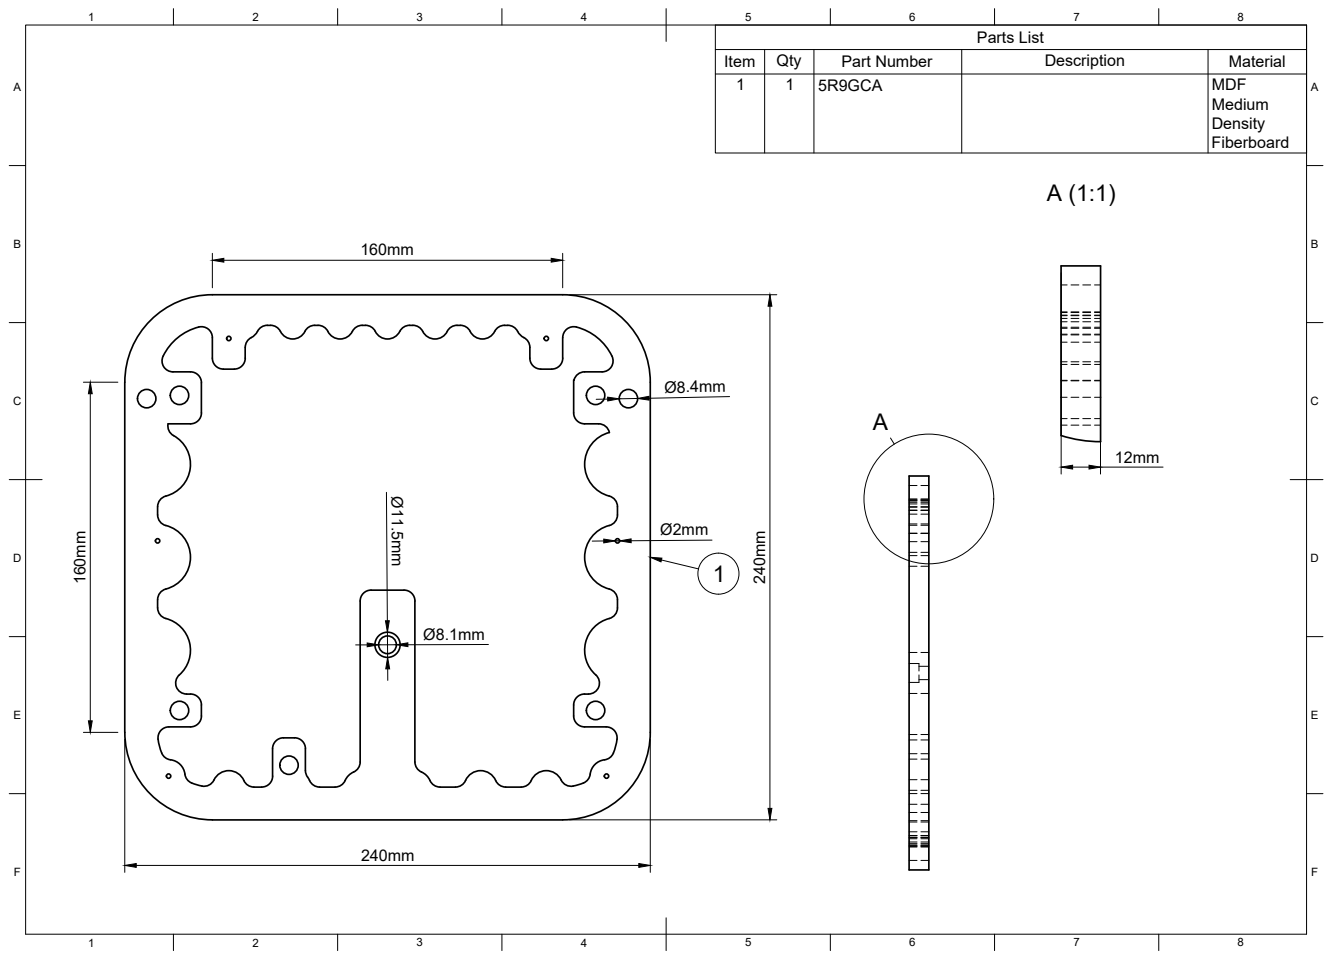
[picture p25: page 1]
Parts List

Item | Qty | Part Number | Description | Material
1 | 1 | 5R9GCA | | MDF Medium Density Fiberboard

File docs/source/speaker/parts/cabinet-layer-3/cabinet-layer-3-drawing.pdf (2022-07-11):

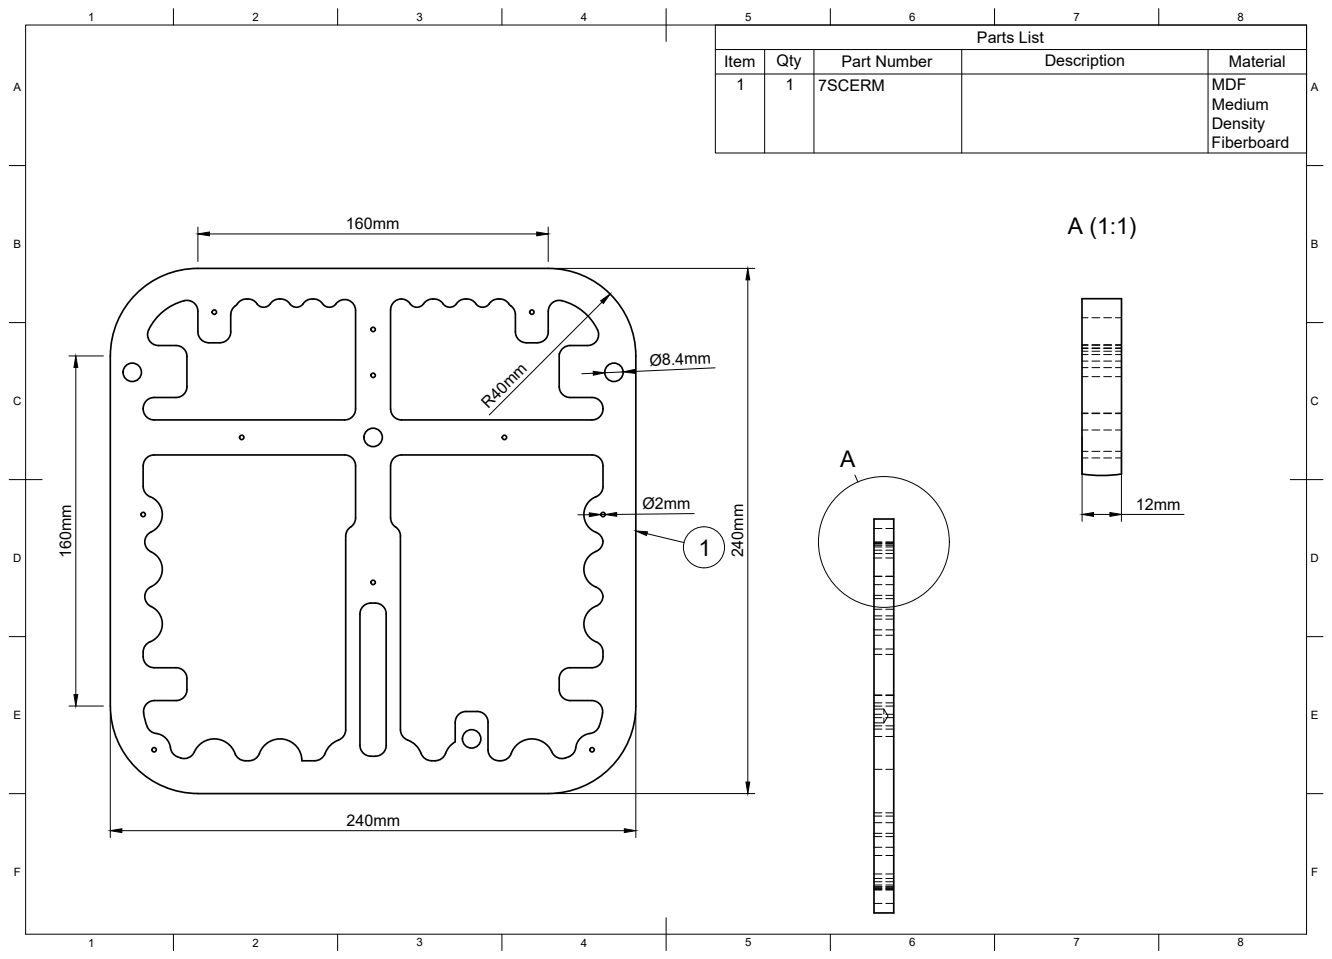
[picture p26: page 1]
Parts List

Item | Qty | Part Number | Description | Material
1 | 1 | 7SCERM | | MDF Medium Density Fiberboard

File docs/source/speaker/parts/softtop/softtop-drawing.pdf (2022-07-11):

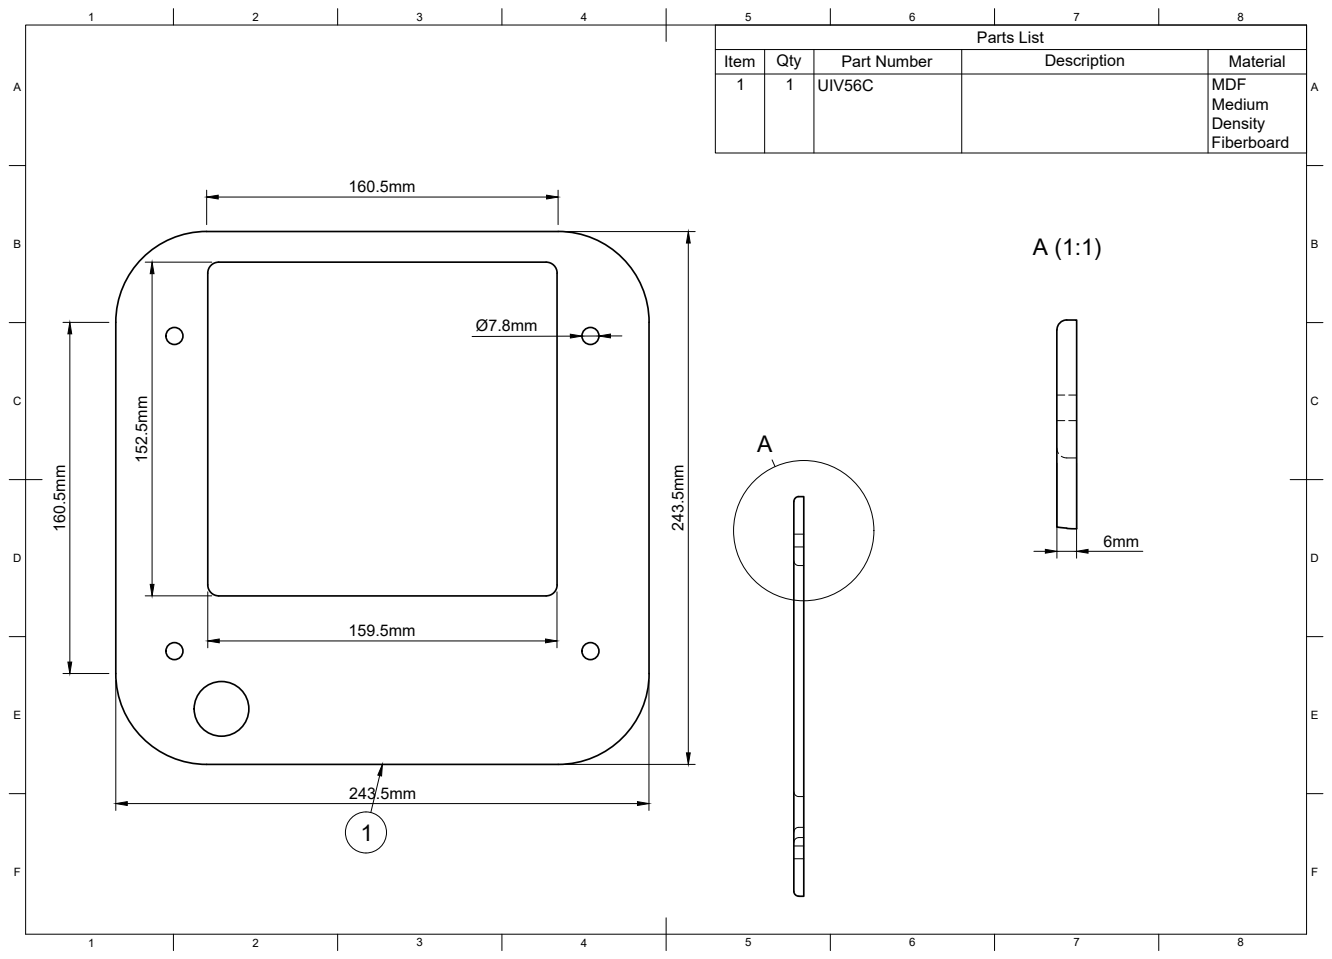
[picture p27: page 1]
Parts List

Item | Qty | Part Number | Description | Material
1 | 1 | UIV56C | | MDF Medium Density Fiberboard

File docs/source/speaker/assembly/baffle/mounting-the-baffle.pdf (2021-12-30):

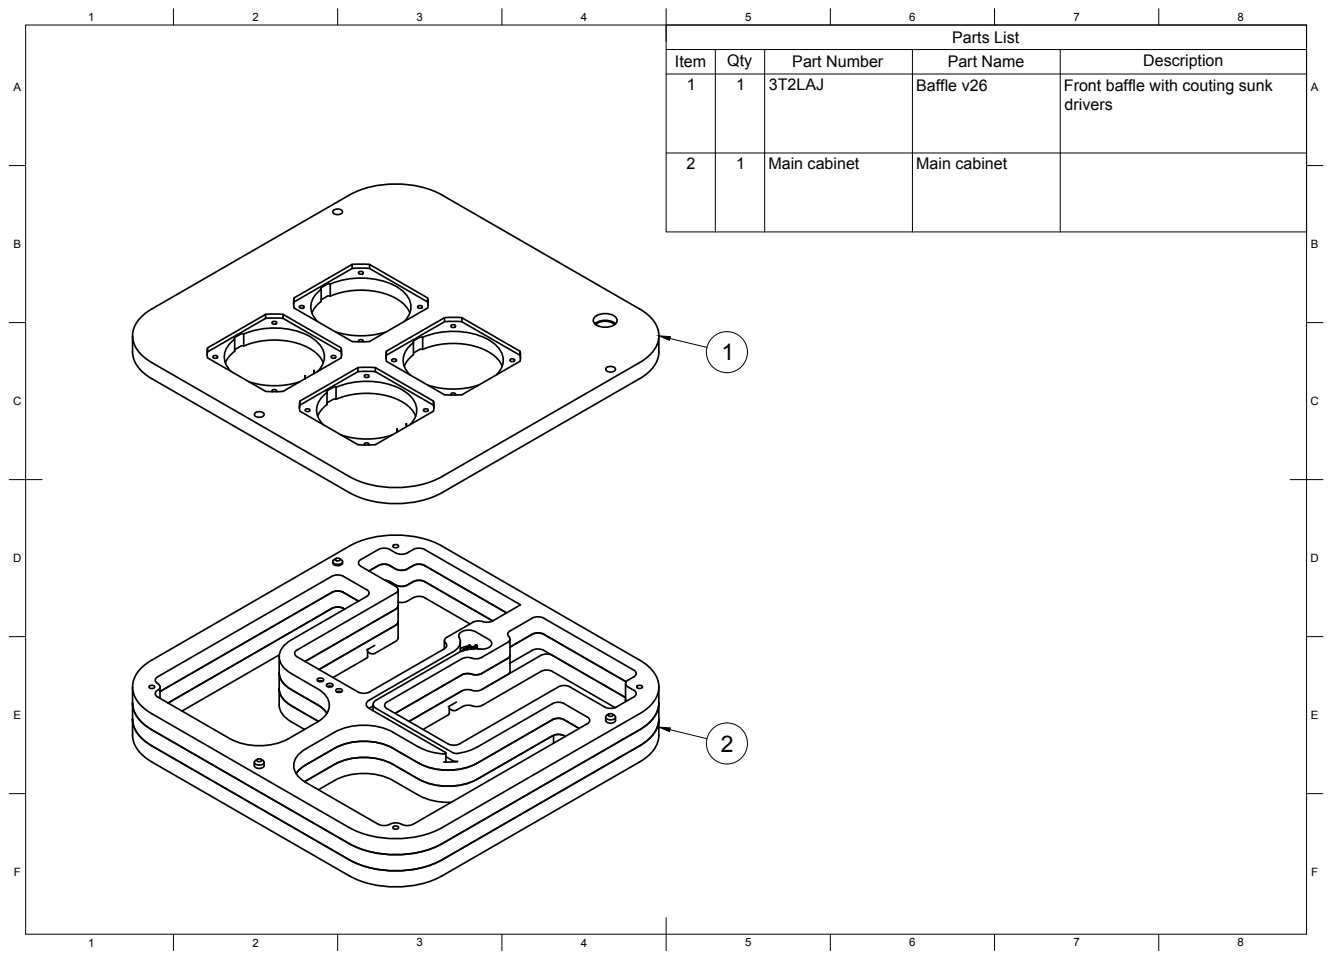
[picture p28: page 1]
Parts List

Item | Qty | Part Number | Part Name | Description
1 | 1 | 3T2LAJ | Baffle v26 | Front baffle with couting sunk drivers

2 | 1 | Main cabinet | Main cabinet

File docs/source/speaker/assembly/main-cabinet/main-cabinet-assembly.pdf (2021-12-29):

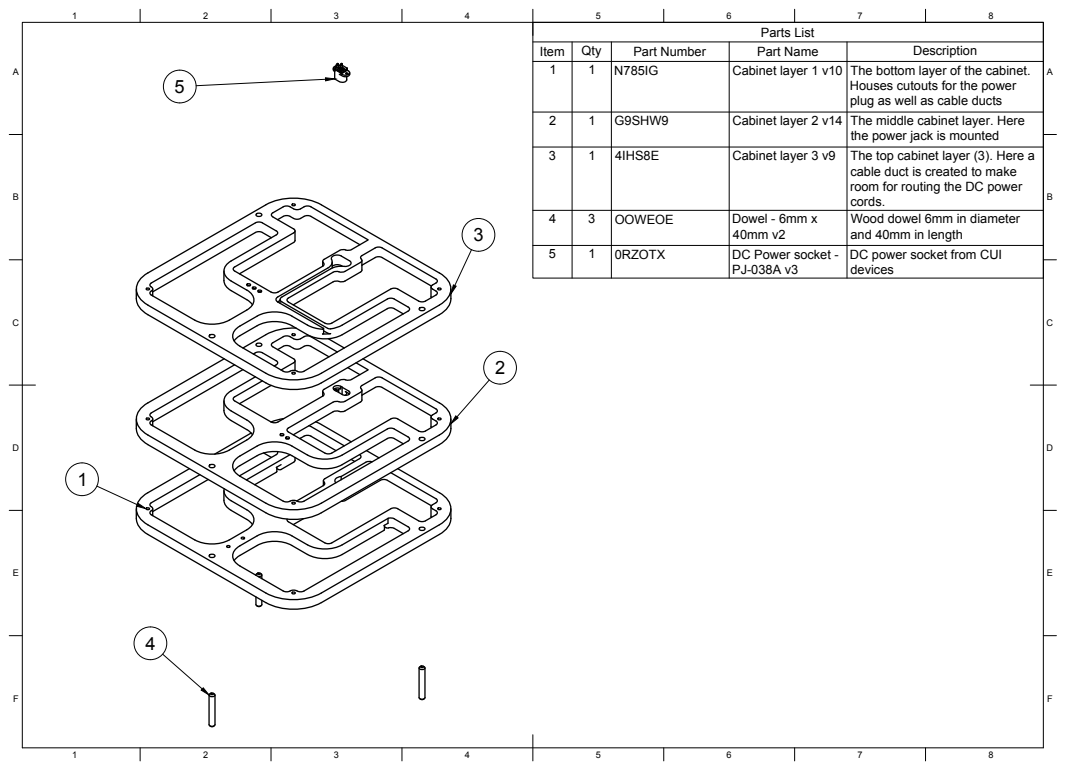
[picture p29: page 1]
Parts List

Item | Qty | Part Number | Part Name | Description
1 | 1 | N785IG | Cabinet layer 1 v10 | The bottom layer of the cabinet. Houses cutouts for the power plug as well as cable ducts

2 | 1 | G9SHW9 | Cabinet layer 2 v14 | The middle cabinet layer. Here the power jack is mounted

3 | 1 | 4IHS8E | Cabinet layer 3 v9 | The top cabinet layer (3). Here a cable duct is created to make room for routing the DC power cords.

4 | 3 | OOWEOE | Dowel - 6mm x 40mm v2 | Wood dowel 6mm in diameter and 40mm in length

5 | 1 | 0RZOTX | DC Power socket -PJ-038A v3 | DC power socket from CUI devices

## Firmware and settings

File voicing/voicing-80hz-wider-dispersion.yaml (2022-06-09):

---
devices:
  samplerate: 44100
  chunksize: 8192
  capture:
    type: CoreAudio
    channels: 2
    device: "Soundflower (2ch)"
    format: FLOAT32LE
  playback:
    type: CoreAudio
    channels: 2
    device: "Built-in Output"
    format: FLOAT32LE
    #format: S16LE

mixers:
  mono:
    channels:
      in: 2
      out: 2
    mapping:
      - dest: 0
        sources:
          - channel: 0
            gain: -6
            inverted: false
          - channel: 1
            gain: -6
            inverted: false
      - dest: 1
        sources:
          - channel: 0
            gain: -6
            inverted: false
          - channel: 1
            gain: -6
            inverted: false

filters:
  LR_highpass_60:
    type: BiquadCombo
    parameters:
      type: LinkwitzRileyHighpass
      freq: 52
      order: 8
  LR_lowpass:
    type: BiquadCombo
    parameters:
      type: LinkwitzRileyLowpass
      freq: 3500
      order: 4
  HS_1_negative:
    type: Biquad
    parameters:
      type: Highshelf
      freq: 100
      gain: -10
      slope: 12
  HS_2_positive:
    type: Biquad
    parameters:
      type: Highshelf
      freq: 1800
      gain: 9
      slope: 12
  HS_2_negative:
    type: Biquad
    parameters:
      type: Highshelf
      #freq: 4500
      #gain: -4.5
      freq: 3230
      gain: -6
      slope: 6
  HS_3_negative:
    type: Biquad
    parameters:
      type: Highshelf
      freq: 350
      gain: -1.4
      slope: 6
  peak_1:
    type: Biquad
    parameters:
      type: Peaking
      freq: 78
      gain: 10
      q: 3
  peak_2:
    type: Biquad
    parameters:
      type: Peaking
      freq: 185
      gain: -3.8
      q: 2
  peak_3:
    type: Biquad
    parameters:
      type: Peaking
      freq: 650
      gain: 4
      q: 6
  peak_4:
    type: Biquad
    parameters:
      type: Peaking
      freq: 529
      gain: -3.5
      q: 6
  peak_5:
    type: Biquad
    parameters:
      type: Peaking
      freq: 1415
      gain: -2
      q: 2.5
  peak_6:
    type: Biquad
    parameters:
      type: Peaking
      freq: 60
      gain: 6
      q: 5
  peak_7:
    type: Biquad
    parameters:
      type: Peaking
      freq: 3200
      gain: 3
      q: 5
  peak_8:
    type: Biquad
    parameters:
      type: Peaking
      freq: 6600
      gain: 3
      q: 3

  gain_to_normal_level:
    type: Gain
    parameters:
      gain: -5

pipeline:
  - type: Mixer
    name: mono
  - type: Filter
    channel: 0
    names:
      - LR_highpass_60
      - LR_lowpass
      - HS_1_negative
      - HS_2_positive
      - HS_2_negative
      - HS_3_negative
      - peak_1
      - peak_2
      - peak_3
      - peak_4
      - peak_5
      - peak_6
      - peak_7
      - peak_8
      - gain_to_normal_level

#      - HS_1_negative
#      - HS_2_positive
#      - HS_3_positive
#      - LS_1_positive
#      - peak_1
#      - peak_2
#      - peak_3
#      - peak_4
#      - peak_16k
#      - peak_5

  - type: Filter
    channel: 1
    names:
      - LR_highpass_60
      - HS_1_negative
      - HS_2_positive
      - HS_2_negative
      - HS_3_negative
      - peak_1
      - peak_2
      - peak_3
      - peak_4
      - peak_5
      - peak_6
      - peak_7
      - peak_8
      - gain_to_normal_level

#      - HS_1_negative
#      - HS_2_positive
#      - HS_3_positive
#      - LS_1_positive
#      - peak_1
#      - peak_2
#      - peak_3
#      - peak_4
#      - peak_16k
#      - peak_5

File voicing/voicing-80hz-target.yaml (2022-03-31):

---
devices:
  samplerate: 44100
  chunksize: 8192
  capture:
    type: CoreAudio
    channels: 2
    device: "Soundflower (2ch)"
    format: FLOAT32LE
  playback:
    type: CoreAudio
    channels: 2
    device: "Built-in Output"
    format: FLOAT32LE
    #format: S16LE

mixers:
  mono:
    channels:
      in: 2
      out: 2
    mapping:
      - dest: 0
        sources:
          - channel: 0
            gain: -6
            inverted: false
          - channel: 1
            gain: -6
            inverted: false
      - dest: 1
        sources:
          - channel: 0
            gain: -6
            inverted: false
          - channel: 1
            gain: -6
            inverted: false

filters:
  LR_highpass_60:
    type: BiquadCombo
    parameters:
      type: LinkwitzRileyHighpass
      freq: 45
      order: 8
  HS_1_negative:
    type: Biquad
    parameters:
      type: Highshelf
      freq: 117
      gain: -10
      slope: 6
  HS_2_positive:
    type: Biquad
    parameters:
      type: Highshelf
      freq: 506
      gain: 2.9
      slope: 6
  HS_3_positive:
    type: Biquad
    parameters:
      type: Highshelf
      freq: 2000
      gain: 5
      slope: 12
  LS_1_positive:
    type: Biquad
    parameters:
      type: Lowshelf
      freq: 173
      gain: 2.0
      slope: 6
  peak_1:
    type: Biquad
    parameters:
      type: Peaking
      freq: 675
      gain: 4.5
      q: 3
  peak_2:
    type: Biquad
    parameters:
      type: Peaking
      freq: 78
      gain: 9
      q: 2.4
  peak_3:
    type: Biquad
    parameters:
      type: Peaking
      freq: 96
      gain: 4
      q: 3
  peak_4:
    type: Biquad
    parameters:
      type: Peaking
      freq: 180
      gain: -2.3
      q: 3
  peak_16k:
    type: Biquad
    parameters:
      type: Peaking
      freq: 15000
      gain: -3
      q: 3
  peak_5:
    type: Biquad
    parameters:
      type: Peaking
      freq: 1000
      gain: 1.3
      q: 0.8
  gain_to_normal_level:
    type: Gain
    parameters:
      gain: -6

pipeline:
  - type: Mixer
    name: mono
  - type: Filter
    channel: 0
    names:
      - LR_highpass_60
      - HS_1_negative
      - HS_2_positive
      - HS_3_positive
      - LS_1_positive
      - peak_1
      - peak_2
      - peak_3
      - peak_4
      - peak_16k
      - peak_5
      - gain_to_normal_level
  - type: Filter
    channel: 1
    names:
      - LR_highpass_60
      - HS_1_negative
      - HS_2_positive
      - HS_3_positive
      - LS_1_positive
      - peak_1
      - peak_2
      - peak_3
      - peak_4
      - peak_16k
      - peak_5
      - gain_to_normal_level

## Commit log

2021-12-14 updating filters with bass boost and eq!
2021-12-19 Adding logic to visualize acoustic measurements
    [initial-voicing-results.csv]
2021-12-21 Adding drawings for parts and a way to convert pdf's to images (WIP)
    [back-panel.step]
2021-12-22 moving things arounds, adding more details on the parts and adding a logo
    [baffle.step, cabinet-layer.step]
2021-12-28 writing about the now three different layers
    [cabinet-layer-1.step, cabinet-layer-2.step, cabinet-layer-3.step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]
2021-12-28 adding info on the power socket
    [CUI_DEVICES_PJ-038A.step]
2021-12-29 adding an assembly guide for the main cabinet
2021-12-30 adding descrption of mounting the baffle
2022-02-21 adding a small correction
    [voicing-dsp-filters.yaml]
2022-03-27 Simulating for 80Hz (#16)
    * Removing not so relevant file and renaming the other one, so other simulations can be mapped.
    * dding back file
    * moving CAD files to dedicated directory
    * adding newly designed CAD files
    * updating documentation
    * adding new parts
    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
    [80hz-target-measurement-initial-filters.csv, 80hz-target-measurement-no-filters.csv, back-panel.step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]
2022-03-31 Feature/dispersion measurement (#19)
    * Just assembled the cabinet
    and managed to get some sound into it.
    A few filter changes have been added to produce are more 'natural' sound. Will need to followup with some actual measurements
    * adding measurement data and new filter configs for the 80Hz target cabinet. As well as some updated documentation.
    * adding latest version of the CAD files
    * adding new part and updating id
    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
2022-04-01 updating analyssi with drivers
2022-04-06 5 best possible integration of the power plug in the cabinet (#20)
    * updating models to add feature for housing the DC socket
    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
    [CUI_DEVICES_PJ-038A.step, cabinet-layer-1.step, cabinet-layer-2.step]
2022-07-11 adding V6 versions of all parts as well as some new files for existing parts (#28)
    [back-panel.step, baffle-elipse-support-bottom.step, baffle-support.step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]
2022-08-12 updating config to increase bass performance and setting amp power profile 2 per default
2022-10-02 Doc/adding missing parts (#35)
    * adding initial description of the mounting hardware
    * addressing version problems by updating to latest available versions
    * Adding pcb standoff
